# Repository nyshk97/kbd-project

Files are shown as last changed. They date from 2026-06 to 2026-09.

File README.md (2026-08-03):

# kbd-project

自分用の最高のキーボードを作るための、自作分割キーボードプロジェクト。
量産・販売は目的にしない。

## 概要

- 個人利用を最優先し、一般化・量産性・販売価格の最適化は優先しない
- 最終形は**左右分割・ロースタッガード・完全無線**に、**Apple Magic Trackpadを中央に統合**した一体型ケースを目指す
- 電源は**乾電池（エネループ単4×2）**。充電の管理から解放されることを要件にする
- 最初から最終形を作らず、簡単な試作を複数台作って段階的にリスクを潰す
- ファームウェアは**ZMK**、MCUは**Raytac MDBT50Q-1MV2 直付け**、スイッチは**Kailh Choc V2（19mmピッチ）**

方針の変遷と、そう決めた理由は `docs/decisions.md` に記録している。

## 進捗

- [x] 最終形の方向性整理
- [x] 段階試作向けのディレクトリ構成
- [x] p01-simple-split: ZMK + XIAO nRF52840 + Choc v1 + 分割 + 親指キー → **保留**（学習目的は達成済み）
- [x] p02-auto-kdk: Auto-KDKで設計した64キー無線分割 → **保留**（PCBの疎通確認まで。スイッチ未装着で打てる状態ではない）
- [ ] **p03: 中央トラックパッド統合・フルスクラッチ** ← 次に着手
- [ ] target: 最終統合版（p03がそのままtargetになる可能性が高い）

p01・p02は未完成のまま保留としたが、放置ではなく判断として記録している。理由は各 `build-log.md` の「保留」節を参照。

次にやることの詳細は `docs/roadmap.md` を参照。

## ディレクトリ構成

使うものだけを置く最小構成にする。

- `docs/` : プロジェクト全体の方針・ロードマップ・意思決定
  - `decisions.md` : 設計判断とその理由（**このプロジェクトの中心的なドキュメント**）
  - `roadmap.md` : 試作ごとの目的と作業順序
  - `parts.md` / `target.md` : 部品メモ、旧方針の最終形メモ
- `boards/p01-simple-split/` : 初号機（保留）。目的・部品表・作業ログ・ZMK設定
- `boards/p02-auto-kdk/` : 2号機（保留）。Auto-KDK生成データ一式・発注記録・作業ログ
- `target/` : 最終的に目指す統合版。旧方針のKLE/Ergogen成果物はレイアウト検討の参考資料として残す

p03のディレクトリは着手する時点で追加する。まだ使わないディレクトリは作らない。必要になった時点で、各試作機の配下に次を追加する。

- `layout/` : KLEや物理配列メモ
- `pcb/` : KiCadファイル、GerberなどのPCB成果物
- `case/` : ケース3Dデータ、印刷用データ
- `firmware/` : ZMK設定ファイル
- `keycaps/` : キーキャップ3Dデータ

試作をまたいで再利用するものが出てきたら `shared/` を作る。外部資料や生成スクリプトが必要になったら `vendor/` や `tools/` を作る。

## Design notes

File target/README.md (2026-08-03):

# target

最終的に目指す統合版の設計データを置く。

**現状（2026-08-03）**: ここに置いてあるKLEレイアウトとErgogen設定は、**初期の旧方針（Ergogen + KiCadでのフルスクラッチ、Choc v1、トラックボール）に基づく成果物**であり、現行方針とは一致しない。レイアウト検討の参考資料として残している。

現行方針では、キーレイアウトの正本は `../boards/p02-auto-kdk/split-us60pct.json`（Choc V2 19mmピッチ・64キー）。次の試作 p03 でもこれをほぼそのまま使う。

**p03がそのままtargetになる可能性が高い**ため、このディレクトリに新たな成果物を置くかは p03 の進行を見て決める。

関連ドキュメント:

- `../docs/decisions.md` : 設計判断とその理由（現行方針の正本）
- `../docs/roadmap.md` : 試作ごとの目的と作業順序
- `../docs/target.md` : 旧方針の最終形メモ（旧方針と明記済み）

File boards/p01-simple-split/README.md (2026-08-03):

# p01-simple-split

ZMK、XIAO nRF52840、Choc v1、左右分割、親指キーの基本フローを掴むための初号機。

> ⚠️ **2026-08-03: 未完成のまま保留にした。** 下記の目的（ZMKのビルド・書き込み・split設定、Chocソケットのはんだ付け、JLCPCB発注）は**すべて達成済み**で、残るXIAOのdirect mountはんだ付けのみ未実施。完成させない判断の理由と残る資産は `build-log.md` の「保留」節を参照。
> 以下の内容は当時の計画書としてそのまま残している。

## 確定仕様

- 無線分割
- ZMK
- Corne Xiao系42キー
- Kailh Choc v1
- Seeed Studio XIAO nRF52840
- トラックボールなし
- エンコーダーなし
- BLEドングルなし
- XIAO nRF52840 Plusなし

## 目的

- ZMKのビルド、書き込み、左右分割設定に慣れる
- XIAO nRF52840前提のZMK構成と配線に慣れる
- Choc v1の配列、キースペース、親指キー位置を体感する
- レイヤー運用で数字、記号、矢印を扱えるか確認する
- PCB、ケース、ファームウェア、組み立ての一連の流れを短く一周する

## スコープ

やること:

- 左右分割
- 42キー前後
- 親指キー
- ZMK
- Seeed Studio XIAO nRF52840
- Choc v1

やらないこと:

- BLEドングル
- PMW3610トラックボール
- EVQWGD001エンコーダー
- XIAO nRF52840 Plusの追加GPIO検証
- OLED / RGB
- 独自キーキャップ
- 複雑な立体ケース

## 完了条件

- 全キーが入力できる
- 左右分割通信が安定する
- XIAO nRF52840でZMKのビルド、書き込み、ペアリングができる
- 最低限のレイヤーで日常入力を試せる
- 親指キー位置の良し悪しを記録できる

## 選定固定

部品購入やPCB発注の前に、使うCorne Xiao系設計を1つに固定する。

現時点の方針:

- ハードウェア正本: `JonMuller/gerbers` の `corne-choc-xiao`
- ハードウェア参考: `LeducH/corne-choc-xiao`
- ファームウェア出発点: `wintinue/zmk-corne`

理由:

- `JonMuller/gerbers` が `corne-choc-xiao` の元実装として扱いやすい
- `LeducH/corne-choc-xiao` のGerber/BOM/CPLはJonMuller版と同一で、整理版・ガイド・購入リンクの参考に向く
- `wintinue/zmk-corne` は `config/boards/shields/chipper/` を持ち、`chipper_left` / `chipper_right` のshield定義を含む
- `wintinue/zmk-corne` は42キー向きの `default_transform` を選択済み
- `wintinue/zmk-corne` のActionsは2025-12時点で成功実績がある

確認済み:

- `wintinue/zmk-corne` 由来の設定は、current ZMK向けに `xiao_ble//zmk` へ変更済み
- GitHub Actions run `28447236060` で `chipper_left` / `chipper_right` のUF2生成に成功
- JonMuller `corne-choc-xiao` のGerber/BOM/CPLを固定し、発注・購入チェックリストを `parts.md` に作成済み
- JLCPCBへPCB 5枚 + bottom side部分PCBA 5枚を発注済み

残確認:

- JLCPCBのDFM/PCBAレビューで確認依頼が来た場合は、承認前に内容を確認する
- `J8` に合うバッテリー/ケーブルと極性を確認する
- XIAO direct mountと裏面バッテリーパッド配線の手順を確認する
- 電源スイッチのfootprint寸法を購入前に確認する

確認するもの:

- リポジトリURLとcommit
- Gerberの有無
- BOM
- Choc v1対応か
- XIAO nRF52840対応か
- 左右の基板がリバーシブルか、左右別か
- ZMK shield定義の入手方法
- `build.yaml` のboard/shield例
- ZMK Studio対応の有無
- バッテリー端子、電源スイッチ、リセットスイッチの扱い

注意:

- 無印CorneはPro Micro前提なので、Corne Xiao系と取り違えない
- `Corne Xiao` という公式統一shield名があるわけではなく、作者ごとにshield名が違う
- ZMK公式のcurrent targetではXIAO nRF52840のboardは原則 `xiao_ble//zmk`
- shield名は選定した基板repoの `boards/shields/` 定義に従う
- 外部shieldの場合はzmk-config内にshield定義を置くか、ZMK moduleとして取り込む

## 実行手順

1. Corne Xiao系設計を選定固定する
2. 基板の入手方法を決める。完成品を買うか、GerberからJLCPCB等へ発注する
3. `parts.md` に沿ってBOMと購入先を確認し、不足部品を購入する
4. 工具を準備する。温度調整付きはんだごて、はんだ、フラックス、テスター、ピンセットを前提にする
5. ダイオード、ホットスワップソケット、スイッチ、XIAO、電源まわりの順に組み立てる
6. 各キーと電源まわりの導通をテスターで確認する
7. ZMK configを作る。ZMK CLIまたは基板repoのサンプルconfigを起点にする
8. `build.yaml` に左右ターゲットを追加する。boardは原則 `xiao_ble//zmk`、shieldは基板repoの定義名を使う
9. 最小keymapを書く
10. GitHub Actionsでビルドし、左右の`.uf2`を取得する
11. XIAOをブートローダーモードにして左右それぞれへ`.uf2`を書き込む
12. 左右を同時リセットし、split接続を確認する
13. PCとはcentral側、通常は左手だけをBluetoothペアリングする
14. 全キー入力テストを行う
15. keymapを編集、push、再ビルド、再フラッシュして反復する

## ZMKメモ

- 古い記事やサンプルでは `seeeduino_xiao_ble` など旧board名が出ることがある
- current ZMKのXIAO nRF52840 board targetは `xiao_ble//zmk` を前提に確認する
- 実際に使うboard/shield名は、選定したCorne Xiao系repoと現在のZMK公式ドキュメントを優先する
- 分割構成ではcentral側がPCへHID出力する。peripheral側はPCと直接ペアリングしない

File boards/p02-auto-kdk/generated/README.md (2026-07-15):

# split-us60pct

Generated by [Auto-Keyboard-Design-Kit](https://auto-kdk.pages.dev/)

## Preview

- 3D View

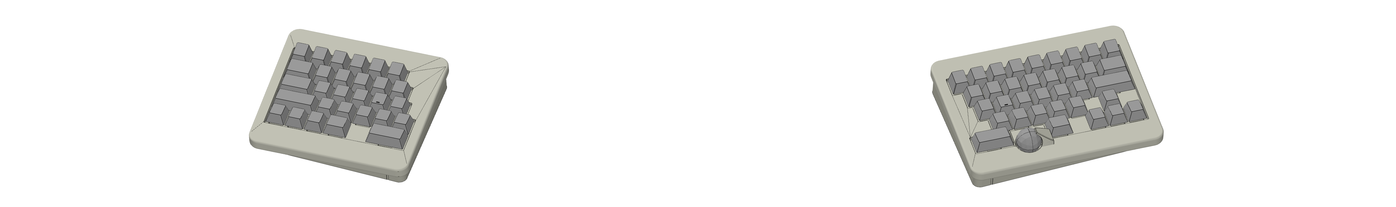
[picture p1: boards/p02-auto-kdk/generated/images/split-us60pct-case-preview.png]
Case Preview


- Top View

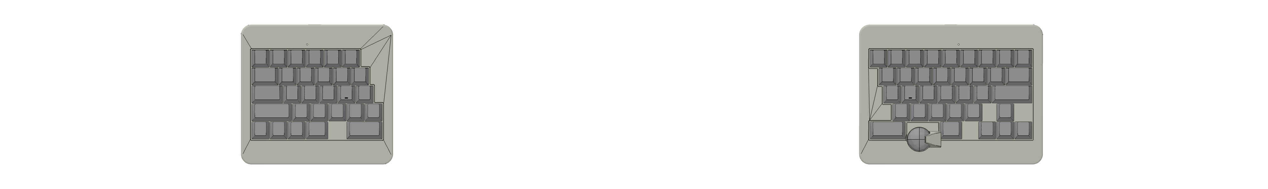
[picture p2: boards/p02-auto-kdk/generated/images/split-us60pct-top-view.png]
Top View


## Parts List

|Part|Quantity|
|---|---|
|wireless controller|2|
|Conthrough(2.5mm, 9pin)|4|
|Battery|2|
USB-C cable|1|
|Choc V2 switch and Choc socket|64|
|Diode|64|
|Keycap|64|

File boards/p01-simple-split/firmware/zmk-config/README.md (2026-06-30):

# **ZMK Firmware for Corne Keyboard (XIAO BLE)**

This repository contains a customized **[ZMK firmware](https://zmk.dev/docs)** for the **Corne split keyboard**(42 keys) powered by **[Seeed Studio XIAO BLE](https://wiki.seeedstudio.com/XIAO_BLE/)**. It includes a custom keymap, multiple layers, and Bluetooth multi-device support.

## **Features**
- 🛠 **Custom Keymap** optimized for efficiency and ergonomics.
- 🔄 **Multiple Layers**: macOS, Windows, Symbols, Numbers, System, and Mouse.
- 📡 **Bluetooth Multi-Device Support** for seamless switching between up to 5 devices.
- 🎭 **Tap & Hold Behavior** for dual-function keys.
- 🖱 **Mouse Layer** for cursor movement and scrolling.
- 🔄 **Firmware Reset & Bootloader Access** via dedicated keys.

---

## **Getting Started**

### **1️⃣ Fork This Repository**

### **2️⃣ Customize Keyboard**
- Using GUI
  - [Keymap Editor](https://nickcoutsos.github.io/keymap-editor/)
- Edit code
  - Edit [`config/chipper.conf`](https://github.com/wintinue/zmk-corne/blob/custom/config/chipper.conf) to set your own keyboard
  - Edit [`config/chipper.keymap`](https://github.com/wintinue/zmk-corne/blob/custom/config/chipper.keymap) to set your own keymap

### **3️⃣ Build Firmware**
1. Click `Action` tab of your repository page.
2. Run `Build ZMK firmware` workflow.
3. Download firmware zip file.

### **4️⃣ Flash Firmware**
1. **Put XIAO BLE into bootloader mode** by double-tapping the [**RST** button](https://wiki.seeedstudio.com/XIAO_BLE/#hardware-overview).
2. Drag and drop the generated `.uf2` file into the mounted **bootloader drive**.

---

## **Keymap Overview**

### **Layer Structure**
| Layer | ID | Function |
|---|----|---|
| **macOS** | `MAC 0` | Default macOS typing layer |
| **Windows** | `WIN 1` | Default Windows typing layer |
| **Symbols & Functions** | `SYM 2` | Special characters, function keys (F1-F12) |
| **Numbers & Navigation** | `NUM 3` | Number pad, navigation keys |
| **System** | `SYS 4` | Media controls, Bluetooth switching, bootloader, reset |
| **Mouse** | `PNT 5` | Mouse movement, scrolling |

---

### **Layer Details**

#### **1️⃣ macOS Layer (`MAC 0`)**
```
 ┌─────┬─────┬─────┬─────┬─────┬─────┐      ┌─────┬─────┬─────┬─────┬─────┬─────┐
 │ TAB │  Q  │  W  │  E  │  R  │  T  │      │  Y  │  U  │  I  │  O  │  P  │BSPC │
 ├─────┼─────┼─────┼─────┼─────┼─────┤      ├─────┼─────┼─────┼─────┼─────┼─────┤
 │CTRL │  A  │  S  │  D  │  F  │  G  │      │  H  │  J  │  K  │  L  │  ;  │CTRL │
 │ ESC │     │     │     │     │     │      │     │     │     │     │     │ '   │
 ├─────┼─────┼─────┼─────┼─────┼─────┤      ├─────┼─────┼─────┼─────┼─────┼─────┤
 │SFT  │  Z  │  X  │  C  │  V  │  B  │      │  N  │  M  │  ,  │  .  │  /  │SFT  │
 └─────┴─────┴─────┼─────┼─────┼─────┤      ├─────┼─────┼─────┼─────┴─────┴─────┘
                   │GUI  │SYM  │SPACE│      │RET  │NUM  │ALT  │
                   └─────┴─────┴─────┘      └─────┴─────┴─────┘
```
- Standard QWERTY layout with `Cmd` (`LGUI`) instead of `Ctrl`.
- **Left Ctrl (`LCTRL`) is dual-purpose**:
  - Tap → `Esc`
  - Hold → `LCTRL`

#### **2️⃣ Windows Layer (`WIN 1`)**
- Identical to macOS, but `Ctrl` and `Win` keys are swapped to match Windows shortcuts.

#### **3️⃣ Symbols & Functions (`SYM 2`)**
```
 ┌───────┬───────┬───────┬───────┬───────┬───────┐      ┌───────┬───────┬───────┬───────┬───────┬───────┐
 │  ~    │  !    │  @    │  #    │  $    │  %    │      │  ^    │  &    │  *    │  (    │  )    │TRANS  │
 ├───────┼───────┼───────┼───────┼───────┼───────┤      ├───────┼───────┼───────┼───────┼───────┼───────┤
 │ PNT   │  F1   │  F2   │  F3   │  F4   │  F5   │      │  F11  │  -    │  =    │  [    │  ]    │  |    │
 ├───────┼───────┼───────┼───────┼───────┼───────┤      ├───────┼───────┼───────┼───────┼───────┼───────┤
 │TRANS  │  F6   │  F7   │  F8   │  F9   │  F10  │      │  F12  │  _    │  +    │  {    │  }    │  \    │
 └───────┴───────┴───────┼───────┼───────┼───────┤      ├───────┼───────┼───────┼───────┴───────┴───────┘
                         │TRANS  │TRANS  │TRANS  │      │TRANS  │SYS    │TRANS  │
                         └───────┴───────┴───────┘      └───────┴───────┴───────┘
```
- **Function keys (`F1-F12`)**
- **Symbol characters** (`@ # $ % ^ & * ...`)

#### **4️⃣ Numbers & Navigation (`NUM 3`)**
```
 ┌───────┬───────┬───────┬───────┬───────┬───────┐      ┌───────┬───────┬───────┬───────┬───────┬───────┐
 │  `    │  1    │  2    │  3    │  4    │  5    │      │  6    │  7    │  8    │  9    │  0    │TRANS  │
 ├───────┼───────┼───────┼───────┼───────┼───────┤      ├───────┼───────┼───────┼───────┼───────┼───────┤
 │TRANS  │ CAPS  │ HOME  │ PGUP  │ DEL   │       │      │ LEFT  │ DOWN  │  UP   │RIGHT  │  |    │TRANS  │
 ├───────┼───────┼───────┼───────┼───────┼───────┤      ├───────┼───────┼───────┼───────┼───────┼───────┤
 │TRANS  │ PSCRN │ END   │ PGDN  │ INS   │       │      │       │       │TRANS  │TRANS  │  \    │TRANS  │
 └───────┴───────┴───────┼───────┼───────┼───────┤      ├───────┼───────┼───────┼───────┴───────┴───────┘
                         │TRANS  │SYS    │TRANS  │      │TRANS  │TRANS  │TRANS  │
                         └───────┴───────┴───────┘      └───────┴───────┴───────┘
```
- **Number keys (`1-0`)**
- **Navigation keys (`Home, End, PgUp, PgDn`)**
- **Arrow keys (`Left, Right, Up, Down`)**

#### **5️⃣ System (`SYS 4`)**
```
 ┌───────┬────────────┬───────┬──────────┬──────────┬───────┐      ┌───────┬───────┬───────┬───────┬───────┬────────┐
 │       │ Play/Pause │ Mute  │ Show Win │ Show App │       │      │       │MAC    │WIN    │       │       │ BT_CLR │
 ├───────┼────────────┼───────┼──────────┼──────────┼───────┤      ├───────┼───────┼───────┼───────┼───────┼────────┤
 │       │ Next       │ Vol+  │ Bright+  │ Search   │ Boot  │      │ Boot  │  BT0  │ BT1   │ BT2   │ BT3   │ BT4    │
 ├───────┼────────────┼───────┼──────────┼──────────┼───────┤      ├───────┼───────┼───────┼───────┼───────┼────────┤
 │       │ Prev       │ Vol-  │ Bright-  │          │ Reset │      │ Reset │       │ BT_PRV│ BT_NXT│       │        │
 └───────┴────────────┴───────┼──────────┼──────────┼───────┤      ├───────┼───────┼───────┼───────┴───────┴────────┘
                              │          │TRANS     │       │      │       │TRANS  │       │
                              └──────────┴──────────┴───────┘      └───────┴───────┴───────┘
```
- **Media controls** (`Play/Pause, Volume, Brightness`).
- **Bluetooth switching:**
  - `BT_SEL 0-4` → Switch to paired devices.
  - `BT_CLR` → Clear Bluetooth pairing.
  - `BT_PRV / BT_NXT` → Cycle through devices.
- **Firmware reset & bootloader mode:**
  - `sys_reset` → Soft reset.
  - `bootloader` → Enters bootloader for flashing firmware.

#### **6️⃣ Mouse (`PNT 5`)**
```
 ┌───────┬───────┬───────┬───────┬───────┬───────┐      ┌───────┬───────┬───────┬─────────┬───────┬───────┐
 │       │       │       │       │       │       │      │ ScrL  │ ScrD  │ ScrU  │ ScrR    │       │       │
 ├───────┼───────┼───────┼───────┼───────┼───────┤      ├───────┼───────┼───────┼─────────┼───────┼───────┤
 │       │       │       │       │       │       │      │ Left  │ Down  │ Up    │ Right   │       │       │
 ├───────┼───────┼───────┼───────┼───────┼───────┤      ├───────┼───────┼───────┼─────────┼───────┼───────┤
 │       │       │       │       │       │       │      │ Back  │       │       │ Forward │       │       │
 └───────┴───────┴───────┼───────┼───────┼───────┤      ├───────┼───────┼───────┴─────────┴───────┴───────┘
                         │       │       │       │      │ LClick│ RClick│ MClick│
                         └───────┴───────┴───────┘      └───────┴───────┴───────┘

```
- **Mouse cursor movement (`MOVE_UP, MOVE_DOWN, MOVE_LEFT, MOVE_RIGHT`)**
- **Scrolling (`SCRL_UP, SCRL_DOWN, SCRL_LEFT, SCRL_RIGHT`)**
- **Mouse clicks (`LCLK, RCLK, MCLK`)**
- **Shortcut keys for browser navigation (`C_AC_BACK, C_AC_FORWARD`)**

---

## **Bluetooth Multi-Device Pairing**

XIAO BLE supports pairing with up to **5 devices**.

### **Pairing New Devices**
1. Activate the **SYS layer** using the assigned key.
2. Select a Bluetooth slot (`BT_SEL 0-4`).
3. Put the keyboard in pairing mode (`BT_CLR`).
4. Connect via your device’s Bluetooth settings.

### **Switching Between Devices**
Once paired, switch devices using:
- `&bt BT_SEL 0` → Device 1
- `&bt BT_SEL 1` → Device 2
- `&bt BT_SEL 2` → Device 3
- `&bt BT_SEL 3` → Device 4
- `&bt BT_SEL 4` → Device 5

---

## **Firmware Reset & Bootloader**

- **Reboot Keyboard:** Press the **reset key** (mapped in `SYS` layer).
- **Enter Bootloader Mode:** Press the **bootloader key** or double-tap the **RST** button.

🔹 `&sys_reset` → Soft reset (restarts the keyboard)
🔹 `&bootloader` → Enters bootloader mode for flashing firmware

- After reset the keyboard, press Space + P | Z to turn on SYS layer
- Further keymap for reset keymap: https://github.com/wintinue/zmk-corne/blob/main/config/boards/shields/chipper/chipper.keymap
---

## **Contributing**
Feel free to submit **issues** or **pull requests** for improvements!

---

## **Credits**
Built using [ZMK Firmware](https://zmk.dev) and inspired by the [Corne Keyboard](https://github.com/foostan/crkbd).

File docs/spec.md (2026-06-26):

# 仕様まとめ

## レイアウト

| 項目 | 内容 |
| ---- | --- |
| 分割 | 左右分割、ロースタッガード |
| 左手 | 6列×5行 + EVQWGD001エンコーダー（escの左） |
| 右手 | 7列×5行 + PMW3610トラックボール（親指エリア） |
| 配列 | US配列、FNキーなし、英数・かなキーなし |

KLEレイアウトはキー数・キー順・ラベルの基準として扱う。Ergogen上の物理座標、列スタッガー、親指キー位置、トラックボール位置は1:1印刷プロトタイプで確認しながら調整する。

## KLEレイアウト

### 左手側

```json
[{a:5,f:5},"`\n~","!\n1","@\n2","#\n3","$\n4","%\n5"],
[{x:0.5,a:7,f:5},"tab","Q","W","E","R","T"],
[{x:0.75,a:4,f:2},"ctrl",{a:7,f:5},"A","S","D","F","G"],
[{x:1.25,a:4,f:2},"shift",{a:7,f:5},"Z","X","C","V","B"],
[{x:1.5,a:4,f:2},"esc","caps","opt","⌘","space"]
```

### 右手側

```json
[{a:5,f:5},"^\n6","&\n7","*\n8","(\n9",")\n0","\"\n'","+\n="],
[{x:0.5,a:7,f:5},"Y","U","I","O","P",{a:5},"{\n[","}\n]"],
[{x:0.75,a:7,f:5},"H","J","K","L",{a:4,f:2,w:1.5},"Enter","_\n-",{a:5,f:5},":\n;"],
[{x:1.25,a:7,f:5},"N","M","<\n,",">\n.","?\n/","↑","|\n\\"],
[{x:1.5,a:4,f:2},"space","⌘","opt",{x:0.75,a:7},"←","↓","→"]
```

## 入力デバイス

| 項目 | 内容 |
| --- | --- |
| スイッチ | Kailh Choc v1 Red（リニア） |
| トラックボールセンサー | PMW3610 |
| トラックボール基板 | SideraKB PMW3610 PCB Rev 2.x系互換 |
| トラックボール径 | 34mm |
| トラックボールクリック | Auto Mouseレイヤー（J・Kキー） |
| スクロール | ボタン押しながらボール転がす |
| エンコーダー | EVQWGD001（左手のみ）レイヤー0=音量、レイヤー1=輝度 |

## 接続・ファームウェア

| 項目 | 内容 |
| --- | --- |
| ファームウェア | ZMK |
| 左右間通信 | BLE |
| PCとの接続 | BLEドングル（USB挿しっぱ） |
| MCU | nice!nano v2 × 3（左右 + ドングル） |

## PCB・ケース

| 項目 | 内容 |
| --- | --- |
| PCB設計フロー | Ergogen → FreeRouting → KiCad最終調整 |
| Ergogen初期成果物 | キー配置 + 外形 + 1:1印刷用アウトライン |
| トラックボール領域  | 34mm円 + 46mm keepout円 + 23.5mm×31.5mm基板矩形 |
| PCB発注 | JLCPCB |
| ケース（フェーズ1） | 3Dプリント（PLA/PETG）、DMM.make or JLCPCB発注 |

## キーキャップ

| 項目 | 内容 |
| --- | --- |
| 1Uキー | MBK市販品（印字なし、フェーズ1） |
| Enterキー（1.5U） | 3Dプリント自作（Choc v1ステム）  |

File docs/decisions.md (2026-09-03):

# 意思決定の記録

## プロジェクト目的：自分用の最高のキーボード

- このプロジェクトは自分用の最高のキーボードを作ることを目的にする
- 量産・販売・第三者向けキット化は目的にしない
- 一般的な使いやすさより、自分の手・作業環境・好みに合うことを優先する
- 部品単価、入手性、製造容易性は考慮するが、量産時の原価最適化やサプライチェーン安定性は優先しない
- 販売向けの認証、パッケージング、ユーザー向け組み立て性、販売後サポートのための設計は対象外にする
- BLE無線モジュールの使用地ごとの法令適合は、販売有無と別に部品選定時に確認する

## 進め方：段階試作

- 最終形を一度で作らず、簡単な試作を複数台作って段階的に近づける
- 各試作機は `boards/pXX-*` に分け、目的・部品表・作業ログを個別に持つ
- 最終形の設計データは `target/` に置き、試作で検証できた要素だけを反映する
- まだ使わないディレクトリは先に作らず、必要になった時点で追加する
- 試作をまたいで使うZMK設定、Ergogen定義、footprint、ケース部品が出てきたら `shared/` を作る

### p01・p02は未完成のまま保留にする（2026-08-03決定）

**両方とも「完成させない」と決めた。** 放置ではなく判断として記録する。各機の詳細は `boards/pXX-*/build-log.md` の「保留」節を参照。

- **p01**: 学習目的（ZMK・split疎通・ソケットはんだ・JLCPCB発注とPCBAのBOM/CPL）は**すべて達成済み**。残るXIAOのdirect mountはんだ付けは、p03では自分のPCBにMCUを載せる設計をするため転用価値が薄い。かつCorne系42キーの別配列は日常運用に投入できず、「1週間使ってみる」ができない。完成させて得られるのは達成感のみと判断
- **p02**: 残作業（バッテリー極性の再工作・トラックボールのモジュール再購入・本番スイッチ64個¥5,000）に対して、得られる検証結果が見合わない。**p03の設計に必要な実測値（左右間隔・奥行きの揃え方・トラックパッド面との高さ差）は、結局p03の実物を3Dプリントして手を乗せないと決まらない**ため、p02を完成させても代替にならない
  - p02で唯一固有に分かるのは**スタビなし幅広キー（2U/2.25U）の実用性**のみ。これは検証対象が4箇所＋比較用1Uが数個なので、**打ち比べで買ったサンプル軸の余りで足りる**（64個の発注は不要）。~~キーキャップが届いた時点で数個だけ挿して確かめる~~ → **検証済み・合格（2026-08-04）**。詳細は「p02レイアウト流用」セクション参照
  - **p02のケース実物は、p03の配置検討モックアップとして価値が残る**（左右間隔・高さを実寸で再現できる唯一の現物）
- 本番スイッチ（~~Pink Island~~ → Islet に変更 2026-08-04）64個の発注は、**p03のキー数とレイアウトが確定してから**行う。先に発注するとp03のPCB論点（XIAOでキー数を減らす vs MDBT50Q直付け）の結論次第で作り直しになる → **レイアウト確定（2026-08-04）により発注可能になった**。YUZUキーキャップは到着済み

## ファームウェア：ZMK

- 完全無線・省電力・Auto Mouseレイヤー・エンコーダー対応が全部揃う
- QMKは有線前提のため非対応
- p01のZMK configはZMK CLIまたは選定したCorne Xiao系repoのサンプルconfigを起点にする
- current ZMKではXIAO nRF52840のboard targetは原則 `xiao_ble//zmk` として確認する
- 古い記事やrepoに残る `seeeduino_xiao_ble` などのboard名は、そのまま使える前提にしない
- Corne Xiao系のshield名は作者ごとに違うため、選定した基板repoの `boards/shields/` 定義を正とする
- 外部shieldはzmk-config内に置くか、ZMK moduleとして取り込む
- 分割構成ではcentral側がPCへHID出力する。peripheral側はPCと直接ペアリングしない
- p01のハードウェア正本は `JonMuller/gerbers` の `corne-choc-xiao` にする
- `LeducH/corne-choc-xiao` は同一Gerber/BOM/CPLの整理版として、ガイド・購入リンクの参考に使う
- p01のファームウェア出発点は `wintinue/zmk-corne` にする
- `wintinue/zmk-corne` の `chipper_left` / `chipper_right` shield定義を起点にし、`build.yaml` のboard名をcurrent ZMK向けに確認・修正する

## MCU：p01はXIAO nRF52840、targetはAuto-KDK専用無線ボード

- p01は無印XIAO nRF52840を使う（変更なし。既存のCorne Xiao系シールドをそのまま使える）
- targetはAuto-KDK採用（2026-07-15、下記PCB設計方針を参照）に伴い、専用無線コントローラボード（nRF52840、IO 18ピン・うち4ピンは拡張モジュールと共用）に変更する
- 専用ボードはBOOTH（のぎけす屋）で無線2個セット¥9,000。一体型・分割とも1セットでよい。コンスルー同梱ではんだ付け不要
- 電源はPHコネクタの1S Li-Po（保護回路必須）、充電200mA、バッテリー最大6×31×52mm
- 旧方針（target向けXIAO nRF52840 Plus候補）は不要になったため撤回

## 接続方式：まずBLE直結、必要になったらドングル追加

- 旧方針はBLEドングル前提（BLE直結はMacとの相性問題・スリープ復帰約5秒の懸念、ドングルはUSB常時接続でほぼ即時復帰）
- p02はBLE直結で使い始める方針に変更（2026-07-15）。ドングルの有無はハードウェアに影響せず、後からファームウェアのビルドターゲット追加＋手持ちの余りXIAO nRF52840の転用だけで移行できるため、スリープ復帰の遅さを実際に体感してから判断する
- ドングル構成がビルド可能かの検証はzmk-config-split-us60pctリポジトリのdongleブランチで実施（dongle/right_p shield、input-splitによるトラックボール中継、XIAOドングル対応）

## スイッチ：p01はChoc v1 Red、targetはChoc V2（19mmピッチ）

- 旧方針はChoc v1 Red（ロープロ最薄・Macの打鍵感に最も近い）だったが、Auto-KDKがChoc v1非対応のため覆した（2026-07-15）
- targetはChoc V2・19mmピッチ。MacBookのキーピッチ（約19mm）を維持して運指の記憶を移行する
- Choc V2はトータルトラベル約3.2mm（バリアントにより2.8mm）・アクチュエーション約1.3mmで、ロープロ最短クラス。MacBook（約1mm）の完全再現ではなく「メカニカルで到達できる最良の近似」と割り切る
- 軸（バリアント）はPCB・ケース設計に影響しないため後から決める。MacBook近似の観点で軽めリニア（Deep Sea Mini Pink Island 35gf / Islet 43gf / Red 45gf前後）を打ち比べ候補にする
- **軸は Kailh Deep Sea Silent MINI Islet（43gf 静音リニア）に決定（2026-08-04）**。YUZUキーキャップ到着後、p02実機にキーキャップ込みで挿して打ち比べた結果 Islet が最良（遊舎工房商品名「Kailh Deep Sea Low Profile Choc V2 サイレントスイッチ 1353 RGB MINI」のIsletバリアント）。~~2026-08-02にキーキャップなしの素のPCB打鍵で Pink Island（35gf）に決定~~ したが、キーキャップの質量が乗ると評価が逆転した（結果的に2026-07-15の当初本命Isletに戻った）。**軸の評価は素のステム打鍵では決まらない。必ずキーキャップを装着して打ち比べる**。「43gf前後の軽めロープロ静音リニアが好み」という知見はステム規格に依存しないため、完成版でMX規格に変えることになっても同等品を指名買いできる
- Choc V2はMXステム。キーキャップ自作はフラット・薄型・広めを狙うとMacBook感が出る
- Choc v1とV2は物理非互換（PCBセンター穴径が違う）ため、p01のPCBにV2は刺さらない。ホットスワップソケット自体は共通で、p01のソケット検品知見は活きる
- 2U以上のキーにはスタビライザーが必要。Choc V2対応ロープロスタビの入手性を確認し、入手困難なら2U以上のキーを置かないレイアウト（親指2Uを分割等）に逃がす

## トラックボールセンサー：PAW3222（target）

- 旧方針のPMW3610（＋SideraKBボード＋34mm固定）はAuto-KDKで選べないため、Auto-KDK標準のPAW3222に覆した（2026-07-15）
- PAW3222は低消費電力で、ZMKドライバ（zmk-driver-paw3222）を開発者sekigon-gonnoc氏自身がメンテしている。無線・バッテリー持ち重視というPMW3610選定理由をそのまま満たす
- ボール径34mm固定は撤回。Auto-KDKのバリエーション（thumb-25 / thumb-34 / index-25〜50）から実配置で選ぶ。径へのこだわりはない
- トラックボール使用時は無線ボードのIOを4ピン消費する（18→実質14）
- **p02では搭載を見送り（2026-08-02）**: 組み立て中にセンサーモジュールのFFCコネクタのラッチを破損。再購入（BOOTH ¥4,500・納期）に見合わないと判断し、キーボード部分の完成を優先した。ボール・支持球・FFC・木工用ボンドは未使用のまま保管してあるので、モジュールだけ買い直せば後から追加できる（ケースにトラックボール穴と支持球座は造形済み）
- **完成版のポインティングデバイスは再検討（未確定 2026-08-02）**: トラックパッドを使う方向で検討中。Auto-KDKはトラックパッドにも対応している（`manual/Trackpad.md`）。ただしp02でトラックボールを実地評価できなかったため、比較材料がない状態での判断になる点は認識しておく。なお中央Magic Trackpad案とトラックボールは**排他ではない**（下記「中央トラックパッド統合ケースの設計メモ」参照）ので、トラックボールを捨てる判断を今する必要はない

## エンコーダー：搭載しない

- 旧方針はEVQWGD001（縦回転スクロールホイール）だったが、必要性が薄れたため搭載しない方針に変更（2026-07-15）
- Auto-KDKにエンコーダーの選択肢がない（EC11・EVQWGD001とも非対応）ことも整合する
- スクロールはトラックボール＋ZMKのスクロールレイヤーで代替する想定

## PCB・ケース設計方針：Auto-KDK

- 旧方針（Ergogen + FreeRouting + KiCad のフルスクラッチ）を覆し、targetはAuto-KDK（sekigon-gonnoc氏のWebツール https://auto-kdk.pages.dev/ ）で設計する（2026-07-15に調査のうえ決定）
- 決定理由: レイアウト指定からPCB（EasyEDA形式json→JLCPCB発注）・ケースSTL・ZMK shield一式（ZMK Studio対応）・フォームカットSVGまで自動生成でき、要件（分割・無線ZMK・ロースタッガード・トラックボール）をネイティブに満たす。特にケース設計の学習コストを丸ごと消せる
- 2026年6月ビルド（ver 2026-06-03）が稼働中のアクティブなプロジェクト。製造到達したユーザー事例も複数あり
- 制約として受け入れたもの:
  - 専用コントローラボード必須（XIAO等の市販MCUボードは選べない）
  - 無線はrow+col合計18ピン上限。トラックボール使用側は実質14ピンで、5行×9列だと上限ちょうど（キー追加不可）
  - PCBデータはEasyEDA形式のためKiCadでの手直し不可。手直しはEasyEDA上で行う
- 未解決事項の確認結果（2026-07-15、データ生成zipで確認）:
  - ライセンス: 解決。利用規約により個人利用・商用利用とも可。ただし生成データは**Auto-KDK公式コントローラとの組み合わせでのみ使用可**。現状有姿・無保証
  - ホットスワップ: 解決。生成PCBにKailh Chocソケット（CPG135001S30）×64 + 1N4148W×64のフットプリントあり。はんだ付けは自分で行う
  - 左手PCB: 解決。left/right/panelized（面付け版）の3種のEasyEDA jsonが生成される
  - スタビライザー: フットプリントなしと判明。Choc V2構成では2U/2.25Uキー（左Shift 2.25U・左親指2U・右2U・右Enter 2.25U）がスタビなしになる → **スタビなしのまま行くと決定（2026-07-15）**。ロープロ＋トラベル3mm＋軽量キャップなら実害は小さい見込みで、「スタビなし幅広キーが実用になるか」自体をp02の検証項目にする。ダメなら次イテレーションで幅広キーを1.5U以下に分割（既存マトリクスの空きセルに収まるためピン数制約には抵触しない）
  - ドングル対応: 解決。zmk-config-split-us60pctのdongleブランチで、dongle shield（central役・モックkscan）＋right_p shield（右手peripheral化・トラックボールをzmk,input-splitで中継）を追加し、akdk_bt1ドングル/XIAOドングル（ZMK v0.3では board名 `seeeduino_xiao_ble`。`xiao_ble//zmk` は新しいZMK mainの名前でv0.3では無効）とも全ターゲットビルド成功（2026-07-15）。必要になったらこのブランチをmainに取り込むだけ
  - 自動配線の品質: 未検証（EasyEDAインポート時に確認）
- 旧方針のErgogen成果物（キー配置・1:1印刷アウトライン）とKLE基準は、レイアウト検討の参考資料として残す

## キーマップ：トラックパッドジェスチャの代替はZMKコンボ

> **完成版では不要になる見込み（2026-08-02）**: Magic Trackpadをケースにはめ込む方針にしたため、macOSのジェスチャーがそのまま使える。下記のコンボはp02（トラックパッドなし構成）でのみ意味を持つ。

- トラックパッド廃止に伴い、4本指スワイプ相当の操作はmacOS標準ショートカット（Ctrl+矢印）をコンボで送る（2026-07-15）
  - J+K = Ctrl+←（左のスペースへ）
  - K+L = Ctrl+→（右のスペースへ）
  - J+K+L = Ctrl+↑（Mission Control。トグルなので閉じるのも同じコンボ）
- Ctrl+↓（App Exposé）は不要と判断。恋しくなったらM+,+.（JKLの真下段）に追加する
- 誤発動対策はrequire-prior-idle、3キー同時が押しにくければtimeout-msを50→80ms程度に調整
- コンボはZMK Studioでは編集できないため`.keymap`に記述してGitHub Actionsでビルドする。レイヤー・キー割り当ての試行錯誤はStudio、確定したコンボはkeymap、という分担

## ケース（フェーズ1）：3Dプリント

- 動作確認フェーズは速度・コスト優先
- DMM.make or JLCPCBに発注
- フェーズ2の素材（アルミ削り出し等）はフェーズ1完了後に検討
- マウントタイプはインテグレーテッド（2026-07-15）。追加部品不要で試作が速く、硬めの打鍵感はMacBook近似の目的とも整合する。ガスケット/Tadpoleの柔らかさが欲しいかはp02を打ってから判断
- Choc V2用の土手（switchEmbankment）はオフで確定（2026-07-15）。見た目と防塵だけの違いで打鍵感に影響しないため、気が変わったらケース再印刷で対応
- p02ケースパラメータ（2026-07-15確定）: チルト5°、テント4°、底面厚さ3mm（強度優先で1.8mmから戻した）、底面縁幅5mm、上面縁幅3mm、角の種類=丸型、R面取り（上部2mm、下部3mm=接地際を削って薄く見せる）。MacBook寄りの柔らかい外観狙い。全てケースSTLのみに影響するため、実物を見て気に入らなければ再印刷で調整

## 完成版の方向性（2026-08-02 更新）

p02を組み上げた経験を踏まえた、完成版の要件イメージ。まだ設計に入る前の方向性であり確定ではない。

### 前提の裏付け：Nuio Flow + Magic Trackpad の実運用経験（2026-08-03 記録）

**「分割キーボードの中央にトラックパッド」という配置は、すでに実運用で検証済み**だった。以前 Nuio Flow（マグネットのデスクパッド上に分割キーボードとトラックパッドを配置するシステム。キーボード$400〜、フルセット$1,000超）と自前の Magic Trackpad を組み合わせて使っていた。

現在は使っておらず手放しているが、**その理由は配置への不満ではなく、周辺の運用への不満だった**：

| 手放した理由 | p03での扱い |
|---|---|
| Nuioの接続が不安定だった | Nuio固有の問題。自作＋ZMKなら自分で制御でき、ドングル構成のビルド検証も済んでいる |
| 充電の管理が面倒だった | **乾電池案（案B）が直接の回答**（下記「薄型化・電源方式」参照。この経験により案Bを本命に格上げ） |
| 机の上にPCの他にキーボード左右＋トラックパッドの3つが増えてごちゃつく | **一体化ケースが直接の回答**。3個バラバラより机がすっきりするという期待がp03の動機そのもの |

**この経験は「トラックパッドを中央に置く配置が自分に合うか」というp03最大の前提リスクを潰している。** 配置は気に入っていて、嫌だったのは接続・充電・散らかりの3点。p03はその3点すべてに設計上の回答を持っている。

なお `docs/decisions.md` の「トラックボールセンサー」の項に「p02でトラックボールを実地評価できなかったため比較材料がない状態での判断」と書いたが、**トラックパッド側については比較材料がないどころか一次の実運用データがある**、と補正する。未評価なのはトラックボールの側。

### 外部キーボードの重要度が上がった（2026-08-03）

Nuio運用時は Mac 1台（MacBook）だけだったが、現在は**自分のMacBook・案件で支給されたMacBook**の2台で、さらに**常時稼働のmac miniを追加予定**。複数台を1組の入力デバイスで扱う必要が出たため、外部キーボードの重要度が当時より上がっている。この変化は下記「複数Mac運用とデバイス切り替え」の論点を生む。

- **トラックパッド + キーボードが一体で綺麗に収まるケース**を自作する。ポインティングデバイスはトラックボールからトラックパッドへ変更を検討（p02でトラックボールを実地評価できなかったため、比較材料がない状態での判断である点は認識しておく）
- **3Dプリンターを導入**してケースを内製する。動機は、p02でJLC3DPに外注したケースが「思ったよりゴツい」と実物で分かったこと。外注は1回$155＋納期がかかり試行回数を稼げないため、手元で回せるようにする
- **左右分割・電池駆動・薄型**は維持（下記「薄型化・電源方式」の検討メモを参照）
- p02で使えたChocソケットのはんだ付け・PCB/PCBA発注・コンスルー接続は、もうハードルではないという自己評価（実績: 128箇所で不良の疑い1箇所のみ）

### 完成版で新たに越える必要があるハードル（3Dプリント技術以外、2026-08-02整理）

難度順。詳細は下記「薄型化・電源方式」の検討メモと重複する部分がある。

1. **PCB設計（回路 + アートワーク）**: コントローラ直付け化＝nRF52840モジュール（Raytac MDBT50Q等）を自分の基板に載せる。アンテナのキープアウト設計を外すとBLEが飛ばず、PCB再発注になる。技適はモジュールの認証でカバーされるが、認証条件どおりのアンテナ周辺設計が前提
   - **2026-08-03: 「最大の壁」という評価を下げる。** 下記「MCUの選択肢」の調査で、失敗リスクを発注前に潰す手段が3つ揃っていることが分かったため（Raytacの無料レイアウトレビュー・公開リファレンス設計・干渉源から離せる配置の自由度）。詳細はそちらを参照
2. **ZMKのボード定義自作**: Auto-KDKは `akdk_bt1` のボード定義を提供してくれていた。自作基板ではZephyrのboard定義（dts / Kconfig / defconfig）を自分で書く必要がある
   - **2026-08-03: 難度が下がった。** `boards/p02-auto-kdk/generated/boards/arm/akdk_bt1/` に生成済みのボード定義一式（dts / Kconfig / defconfig / board.cmake）が手元にあり、**同じnRF52840モジュール搭載ボードの実例としてテンプレートに使える**。GPIOマップ・バッテリー電圧分圧・LEDと必要な要素が一通り揃っている。ゼロから書くのとは難度が違う
3. ~~**トラックパッドの選定とドライバ**~~ → **Apple Magic Trackpad をはめ込む方針に決定（2026-08-02）**。BLEでMacに直接繋がる独立デバイスのため、ZMK側は一切関与しない。**ドライバ・動作電圧・基板実装のハードルが丸ごと消え、機構設計だけの問題になる**。副次的に、macOSのジェスチャーがフルで使えるため「キーマップ：トラックパッドジェスチャの代替はZMKコンボ」の項（J+K = Ctrl+← 等）は**不要になる**。新たに出る課題:
   - ⚠️ **感圧式（Magic Trackpad 2以降）を選ぶこと**。初代の物理ヒンジ式は手前を押し込んでクリックする構造なので、ケースに固定するとクリックできなくなる
   - **厚み 最厚部 約10.9mm / 最薄部 約4.9mm** が薄型化の下限を決める。ただし「奥が厚く手前が薄い」形状はキーボードのチルト方向と一致するので、楔形として一体化できる可能性がある。実測して断面を描いて検証する
   - Appleは3Dモデルを公開していないため寸法は実測が必要。固定方法（落とし込み+爪 / 磁石 / 上下で挟む）、背面の充電ポートと電源スイッチへの開口
   - **配置は左右分割の中央に決定（2026-08-02）**。使うのは現行モデル（感圧式）。帰結として:
     - Magic Trackpadの幅160mmぶん、**左右のキーボードを離す**ことになる（隙間を入れて実質165〜170mm）。一般的な分割キーボードの間隔（150〜250mm）に収まる範囲で、肩が開く姿勢は人間工学的にはむしろ有利
     - **奥行きはトラックパッド114.9mm に対しp02ケースが147.8mm**と33mm差がある。手前/奥/中央のどこで揃えるかは、親指キーとトラックパッドの距離感に効くので設計時に要検討
     - ~~**厚みを完全に揃えるのは努力目標**（2026-08-02）。電池ぶん膨らむのは許容し、デザイン（面の連続性・傾斜・面取り）で処理する方針~~ → **2026-08-03: 現実的な目標に格上げ。** 電源をエネループ**単4**×2（直径10.5mm）に決めたことで、**Magic Trackpadの最厚部10.9mmとほぼ一致する**ため。加えてMCUをMDBT50Q直付け（約2mm、最薄）に決めており、コンスルー約6mmやXIAO約3.5mmの上乗せも消えた。デザインで処理する方針は引き続き有効だが、「膨らむのを許容する」前提から出発する必要はなくなった
4. **乾電池駆動の電気設計**: エネループ2本＝2.4V。nRF52840自体は1.7〜3.6Vで動くが、**トラックパッドICの動作電圧を要確認**（PAW3222で未確定のまま残った論点と同型）。低電圧時の挙動、ZMKの電池残量レポートの校正も必要
5. **機構設計（3Dプリント技術とは別のスキル）**: 寸法公差・嵌合・電池ボックスの蓋と接点・薄型化による剛性低下。プリンターが使えることと、勘合する設計ができることは別

**軽減策**: 上記1・2はAuto-KDKを使い続ければ丸ごと回避できる（ただしコントローラ直付け化と乾電池は不可）。段階を分けて、まず「Auto-KDK + トラックパッド + 自作ケース」で3と5を潰し、その後にフルスクラッチで1・2・4へ進む道もあった。

→ **2026-08-02: フルスクラッチで行くと決定。** 段階分けはせず、次のプロトタイプから自作PCB + 自作ケースに進む。

**Auto-KDKのケースは今回の構成には使えない**点も判断材料になった。Auto-KDKは左右それぞれ独立したケースを生成するだけで、「左右をつなぐ中央部分」は生成しない。Magic Trackpadを中央にはめ込む一体型ケースにする以上、ケースはどのみち完全自作になる。

### 中央トラックパッド統合ケースの設計メモ（2026-07-30 検討、未確定）

上記ハードル3（Magic Trackpadを中央にはめ込む）を機構面から詰めたメモ。寸法はp02のSTLからの実測・概算。

先行例: **Nakaniwa（中庭）** — ABplus生産技術研究所の60%スプリットキット。中央にMagic Trackpadを置くスペースを持つ一体型（遊舎工房 ¥19,800、2021年） https://akiba-pc.watch.impress.co.jp/docs/news/news/1366764.html

- **固定は「載せるだけ」でよい**: Magic Trackpad 2以降はForce Touch（感圧＋ハプティクス）でクリックに機械可動部がないため、底面を全面支持しても操作感は変わらない。落とし込み+爪や磁石は位置決めのためだけで、クリック機構への逃げは不要
- **傾斜が噛み合う**: トラックパッド表面は手前4.9mm→奥10.9mmで約3°の傾斜があり、p02のチルト5°と方向が同じ。トレイ側で+2°傾ければキー面とほぼ平行にできる
- **必要なリフト量は10〜25mm程度**: p02のキートップは机から手前約20mm・奥内側約30mm強。3Dプリントに無理のない造形量
- **幅がほぼ一致する**: トラックパッド約160×115mmに対し、p02の片手ケースは約160×148mm。左右の間に並べたときの収まりが良い
- **トラックボールと排他ではない**: トラックパッドはMacと直接BLEペアリングする独立デバイスでキーボード側のハード・ファームに影響しないため、後からトラックボールを載せても共存できる（トラックボール = ホームポジションを崩さない細かいポインティング、トラックパッド = ジェスチャ・スクロール、と役割分担）
- **トラックパッド面はキートップとツライチ〜2、3mm低め**が定番（タイピング中の親指誤タッチ回避）。シム／調整脚で±3mm動かせる設計にして実物で追い込む
- 奥の縁にUSB-Cポート＋電源スイッチの逃げ、取り出し用の指掛かり穴を設ける
- 質感の分担: 外装の最終版はJLC3DP SLA（Black Resin）、試行錯誤・土台類は自宅FDM（256mm級ベッドで全パーツ印刷可）

#### ケースの一体化は段階的に上げる

PCBのフルスクラッチは確定だが、**ケースの一体化度合いは安いイテレーションから試す**。最適な左右間隔・角度がまだ実測で分かっていないため。

1. **単独トレイ**: トラックパッドの台のみ。左右キーボードは自由配置のまま
2. **耳付き中央ユニット**: トレイの左右にケース内縁の位置決めガイドを伸ばす
3. **フルベース板**: 左右ケースの底がはまる凹み付きの板。置けば必ず同じ配置が再現される。500mm超の一枚ものは家庭用プリンタでは不可能（JLC3DPでも高価＋反りリスク）なので、中央＋左右翼の3分割印刷をボルト/ダブテールで結合する
4. **完全一体型ケース**: 全部入り筐体。左右間隔・角度・高さの全パラメータが実測で確定した後の最終回答

~~進め方: p02をキーボードとして完成させる → 机上で間隔・角度をしばらく試す → 気に入った配置を実測 → 1の単独トレイから着手~~

> **2026-08-03: この進め方は撤回。** p02は保留とし完成させない（打鍵できる状態にしない）。左右間隔・角度・高さは**p03の単独トレイを3Dプリントして実物で追い込む**方針に変更した。p02のケース実物は、その際の配置検討モックアップとして使う。

### p01/p02の資産の活用可能性（2026-08-02）

**使えるもの:**

- **XIAO nRF52840（p01の予備1個が未使用）**: 使えば**ZMKボード定義の自作（ハードル2）が丸ごと消える**。`xiao_ble//zmk` としてZMK公式サポート、技適取得済み、充電回路内蔵。PCB設計もモジュール直付けよりずっと楽（フットプリントを置いて配線するだけ）
- **ZMK設定の知見**: shield定義・`build.yaml`・GitHub Actionsビルド・キーマップ/コンボ。p01とp02で2回通したのでハードルではない
- **`boards/p01-simple-split/tools/keytest.html`**: キー確認ツール。そのまま使える
- **JLCPCB発注の知見**: Gerber/BOM/CPL、部分PCBA、DFM確認。自分のGerberを出すときに直結
- **Chocソケット（CPG135001S30）**: Choc v1用とV2用で共通。p01の余りは流用可
- **HIOKI 3244-60（テスター）**
- **DTP502535バッテリー2本**: フルスクラッチなら配線を自分で作るので、p02で踏んだ極性問題も起きない
- **p01のPCB（JonMuller/gerbers の corne-choc-xiao）**: レイアウトが違うので直接流用は不可だが、**XIAOのフットプリントと配線の実例**として参照価値がある

**使えないもの:**

- Choc v1 Red スイッチ、MBKキーキャップ（Choc v1ステム用。V2はMXステムで非互換）
- ~~Auto-KDK専用コントローラ2枚（専用ボード前提の設計のため、フルスクラッチでは使えない）~~ → **2026-08-03: 撤回。使える可能性がある**（下記「MCUの選択肢」の案A参照）。ライセンス条項は*生成データ*の使用を縛るものなので、「自作PCB＋公式コントローラ」は生成データを使わない以上、対象外の可能性が高い。ただしコンスルーのピン配置を生成PCBデータから読み取るのはグレーなため、作者への確認が必要

## MCUの選択肢（2026-08-03 全面整理、未決定）

旧「⚠️ XIAOを使う場合のキー数制約」を、選択肢の洗い直しにより差し替え。**当初「XIAO vs MDBT50Q直付け」の二択と整理していたが、実際には5つある。**

### 前提：マトリクスに必要なピン数

「行数 + 列数」で決まる。p02のレイアウト（右手5行×9列）は**14本**。

| | ピン数 | 64キー維持 | ZMKボード定義 | 技適 | 乾電池 | 薄さ | 手元 | 追加費用 |
|---|---|---|---|---|---|---|---|---|
| **A. Auto-KDKコントローラ** | 18 | ○ | **不要（生成済み）** | ○ 済 | ✗ 充電回路内蔵 | ✗ 約6mm | **2枚あり** | **¥0** |
| **B. XIAO 無印** | 11 | ✗ | 不要（公式） | ○ 済 211-220207 | ✗ 充電回路内蔵 | △ 約3.5mm | **3個あり** | **¥0** |
| **C. XIAO Plus** | 20 | ○ | ほぼ不要 | **要確認** | ✗ 充電回路内蔵 | △ | なし | 約¥4,000（$10.40/個） |
| **D. MDBT50Q-1MV2 直付け** | 豊富 | ○ | 要自作（テンプレあり） | ○ 済 | **○ 載せない選択可** | ○ 約2mm | なし | 約¥3,400 |
| **E. charlieplex配線** | — | ピン制約を撤廃 | — | — | — | — | — | — |

- **C（XIAO Plus）**: 11本のスルーホール＋9本のSMDキャステレーション＝多機能ピン20本。**「XIAOだとキー数が減る」という旧前提を覆す**。ただし**技適が未確認**（無印は211-220207で取得済みだが、Plusは基板レイアウトが変わっており同一認証でカバーされるか不明）。**技適がなければ日本で使えないので選択肢ごと消える**。総務省の技適検索かSeeed公式の認証書類で要確認
- **E（charlieplex）**: 他と直交する選択肢。ZMKに `zmk,kscan-gpio-charlieplex` ドライバが実在し、n本のピンで n×(n-1) キー（interrupt-gpios使用時は (n-1)×(n-2)）を駆動できる。**XIAO無印の11ピンでも90キー**。ただし配線が複雑になりPCB設計の難度が上がる
- 旧案の**I/Oエキスパンダ**は、Eのほうが素直なため優先度を下げる

### 価格差は判断材料にならない

**最大差が¥4,000**で、プロジェクト全体（3Dプリンター¥126,000 / Magic Trackpad ≒¥19,800 / PCB+PCBA $100〜200 / スイッチ¥5,000 / キーキャップ≒¥10,000）の1〜2%にすぎない。**MCU選択を価格で決めるのは筋が悪い。**

実質的なコスト差は別のところにある — **Dの本当の価格は「アンテナ設計を外したときのPCB再発注」（$100〜200＋納期2〜3週間）**であり、部品代¥3,400よりずっと大きい。ただし下記の通り、これは事前に潰せる。

参考価格: A = 2個セット¥9,000（BOOTH）/ B = ¥1,780（秋月、3個¥5,340の実績）/ C = $10.40（Seeed、10個以上で$8.40）/ D = ¥1,185（マルツ）〜¥1,265（スイッチサイエンス）＋周辺部品¥350〜500/枚（USB-Cレセプタクル・ESD保護・リセットSW・電源SW・デカップリング・分圧抵抗。**乾電池直結ならレギュレータと充電ICは不要**）

### 決定的な論点：乾電池と充電回路の衝突

**A・B・C はいずれもLi-Po用の充電回路を内蔵している。** 乾電池を繋ぐとUSB接続時に充電ICがエネループへリチウム用の充電プロファイルを流すことになり危険。さらに電圧の成立性も既製ボードでは保証されない:

| | 給電経路 | 2.4Vで成立するか |
|---|---|---|
| A | PHコネクタ → 充電IC → ? | **回路図が非公開**。LDOが入っていればドロップアウトで不安定。確認手段が実測しかない |
| B/C | BAT端子 → 充電IC(BQ25101) → LDO → 3V3 | BAT端子は使えない。3V3ピンへの直接給電なら動く可能性があるが、電源回路への逆流とスリープ時消費電流が懸念 |
| **D** | **電池 → モジュールのVDD 直結** | **○ レギュレータも充電ICも載せない設計にできる。変換ロスゼロ** |

エネループ2本は満充電2.8V→公称2.4V→終止2.0Vで、nRF52840の動作範囲（1.7〜3.6V）に全域が収まる。問題はチップの手前の電源回路であり、A〜Cは「他人が設計した電源回路に想定外の電圧源を横から突っ込む」形になる。**乾電池を要件に据えるならDに一本化される。**

昇圧IC（2.4V→3.3V）でA〜Cを生かす逃げ道はあるが、常時待機電流を食い無線の省電力と相性が悪いため勧めない。Dなら昇圧そのものが不要。

### D（MDBT50Q）のアンテナ設計は、当初評価より容易

キープアウトの実要件はシンプルで、**アンテナの真下と周辺にグランド・配線・電源プレーンを置かない**（多層基板なら該当領域から全レイヤーのベタを抜く）こと。データシートの表現は "No ground pad should be included in the corresponding position of the antenna. The No-Ground-Pad area should be as wide as you can."

失敗リスクを発注前に潰す手段が3つある:

1. **Raytacが無料でレイアウトレビューをしてくれる**。データシートに、レイアウトをPDFで `service@raytac.com` に送ればアンテナ設計要件への適合をチェックする旨が明記されている。JLC3DPのReview Before Paymentと同じ構図で、既に経験済みの進め方
2. **公開リファレンス設計がある**: `siderakb/mdbt-micro`（MDBT50Q使用のnRFMicro/ProMicro互換ボード）、ErgoSNM（MDBT50Q使用のキーボード）、Skean（E73 nRF52833の完全無線分割キーボード）。アンテナ周辺のレイアウトを実績のある設計から写せる
3. **この構成は干渉源から離しやすい**（下記）

### 本構成での電波干渉の評価

| 干渉源 | 評価 |
|---|---|
| 乾電池（エネループ単3×2）＝金属の塊 | **回避可能**。案Bは電池を後端配置のため、MCUを前端に置けば最も離れる |
| Magic Trackpad＝アルミ筐体が中央にある | **回避可能**。左右それぞれのMCUを**外周側**に置きアンテナを外に向ければ最も遠くなる |
| 3Dプリント樹脂ケース | 問題なし（電波を通す）。ただし薄型化で**金属補強板を入れる場合はアンテナ付近を避ける** |

**「MCUを外周側・前寄り、電池を後端」**という配置ひとつで2つの干渉源から同時に離れる。USB-Cポートも外側に来るが、充電・書き込み用なので支障ない。

**残る懸念は左右間通信（central ⇄ peripheral）が中央のアルミ板で遮られないか**。ただし①BLE 2.4GHzは回折・反射し距離160mmは近すぎるほど近い（到達距離は10m級）②先行例のNakaniwaが製品として成立している ③**ドングル構成にすれば左右がそれぞれドングルと通信する形になり、この問題自体が消える**（ビルド検証済み）。

### → D（MDBT50Q-1MV2 直付け）に決定（2026-08-03）

**乾電池要件を確定したことによる一本化。** 上記「決定的な論点：乾電池と充電回路の衝突」の通り、充電回路を載せない選択ができるのはDだけであり、電池直結でレギュレータも不要になる。

決定を後押しした事実:

- Dのアンテナ設計・ボード定義自作のハードルが、当初評価より明確に低いと分かった（Raytacの無料レビュー・公開リファレンス設計・`akdk_bt1` のdtsがテンプレートに使える）
- **Dは薄型化にも最有利**（約2mm。A=約6mm、B/C=約3.5mm）。乾電池直結でレギュレータと充電ICが不要になり部品点数も減る
- 価格差は全体の1〜2%で判断材料にならない
- フルスクラッチ方針（2026-08-02決定）と整合する

**保留**: C（XIAO Plus）の技適確認は、Dに決めたことで不要になった。Dが行き詰まった場合の代替として調べる価値は残る。

**残る作業**（着手時に潰す）:

- Raytacへのレイアウトレビュー依頼（PCB発注前・必須）
- リファレンス設計（`siderakb/mdbt-micro` 等）のアンテナ周辺レイアウトの参照
- `akdk_bt1` をテンプレートにしたZMKボード定義の作成
- 電池電圧測定（分圧抵抗）とZMK電池残量レポートの校正 — 乾電池は放電カーブがLi-Poと違うため、そのままでは残量表示が正しくない

### ウォッチ: XELBO — 乾電池1本駆動のXIAOサイズ互換ボード（開発中、2026-08-07記録）

せきごん氏（@_gonnoc）が開発中の「XELBO」（[発表ツイート](https://x.com/_gonnoc/status/2084975175347613941)、rev.0）。**乾電池1本＋昇圧一体・XIAOサイズ・コンスルー対応**。裏面シルクに「Do NOT connect LiPo」とあり、A〜Cを消した「乾電池と充電回路の衝突」問題を既製ボードのまま回避できる初の選択肢になりうる。

**販売されたらDの決定を一度再評価する。** 論点:

- **XELBOが勝る点**: 電池1本で済む（単4×1本分のスペースが浮く）／コンスルーで実装ミス＝PCB再発注のリスクが消える／XIAOフットプリントのPCBにすれば**手持ちの未使用XIAO nRF52840×3個で先行検証→XELBOに差し替え**という段階的な進め方ができる（p01のXIAOフットプリント実例も流用可）
- **Dが勝る点**: 薄さ（直付け約2mm vs コンスルー実装で7〜10mm級）
- **未確認事項**: 搭載モジュールの技適／昇圧回路のスリープ時待機電流（キーボードは待機電流が電池寿命を支配する）／価格・入手性・頒布時期

2026-08-07時点でWeb上に情報なし（ツイートのみ）。

## キーレイアウト：p02の split-us60pct をほぼそのまま使う（2026-08-03決定）

実データは `boards/p02-auto-kdk/split-us60pct.json`（Auto-KDK形式）。フルスクラッチのPCBを起こす際も、この配置を正とする。

**構成**（jsonから確認した実値）:

- `switchType: choc2-19`（Choc V2・19mmピッチ）、`isSplit: true`、`minStabilizer: 2`
- 左手 5行×6列（29キー） / 右手 5行×9列（35キー） = **計64キー**（US 60%相当）
- 幅広キーの内訳: 左手 1.25u / 1.5u / 1.75u / 2u / 2.25u が各1、右手 1.25u / 1.5u / 2u / 2.25u が各1
  - **2u以上は左右あわせて4箇所**（左2u・左2.25u・右2u・右2.25u）。これが「スタビなし幅広キーの実用性」検証の対象そのもの

**MDBT50Q採用によりピン制約が消えた**ため、Auto-KDK時代の「無線18ピン上限・トラックボール使用側は実質14ピンで追加不可」という縛りは無関係になった。キーの追加・分割は自由に決められる。

### トラックボール廃止による変更点

p02では右手のみにトラックボールを配置していた（`variant: thumb-25`、`x: 2.5, y: 4.875, a: 180`、2u×2u相当の占有）。ポインティングをMagic Trackpadに移したことで、**右手の親指クラスタ付近に2u×2uのスペースが空く**。

選択肢は2つで、設計時に決める:

1. **空いた場所にキーを追加する**（ピン制約がないため自由）
2. **ケースを詰めて右手を小さくする** — 左右の外形が揃い、中央トラックパッドとの見た目の対称性が上がる可能性がある

なお、右手だけトラックボール分の面積を持っていたため、**現状の左右ケースは非対称**。中央にトラックパッドを置く構成では左右対称のほうが収まりが良い可能性があり、2を選ぶ動機になる。

### 帰結：YUZUキーキャップが流用できる

レイアウトを維持するため、**p02用に発注したYUZUキーキャップ（`boards/p02-auto-kdk/yuzu-design.json`）がp03でそのまま使える**。以前「p03のキー数次第で作り直し（$64〜80）」と書いた懸念は解消した。Choc V2はMXステムで、キーキャップはスイッチが同じである限り引き継げる。

### ✅ スタビなし検証は合格、レイアウト確定（2026-08-04）

**スタビなし幅広キー（2u/2.25u × 4箇所）の実用性検証は完了。** YUZUキーキャップ到着後、p02実機にサンプル軸＋キーキャップを挿して打鍵し、**問題なし・実用に耐える**と判断した。

- レイアウトは現状（split-us60pct流用）のまま**確定**。キーキャップもそのまま使える
- ~~耐えない場合は2u/2.25uを1.5u以下に分割、キーキャップ再発注~~ この分岐は消滅

残る作業は **本番スイッチ Islet 64個＋予備の発注**（軸は同日の打ち比べで Pink Island から Islet に変更。「スイッチ」セクション参照）。

## 複数Mac運用とデバイス切り替え（方針決定 2026-08-03、実機検証は未実施）

**Mac 3台（自分のMacBook / 案件支給MacBook / 導入予定のmac mini）を1組の入力デバイスで扱う**という要件が新たに判明した。ここに、中央トラックパッド構成に固有の問題がある。

**Magic Trackpadは独立したBLEデバイスなので、キーボードと連動して切り替わらない。**

- キーボード（ZMK）は `BT_SEL 0-4` で5台まで一発切り替えできる（p02のキーマップに実装済み）
- Magic Trackpadには切り替えボタンがなく、**macOSのBluetooth設定から手動で繋ぎ直すしかない**
- 結果、「キーボードはmac miniに、トラックパッドは案件MacBookに繋がったまま」という状態が日常的に起きる
- **一体型ケースにすると見た目は1つのデバイスなのに、中身は独立した2デバイス**というギャップがここで露出する

これは「Magic Trackpadを使う＝ZMK側は一切関与しない」という利点（ドライバ・電圧・基板実装のハードルが消える）の裏返しで、トレードオフとして受け入れた構造から出てくる問題。

### 解決方針：blueutil + ホットキー + ZMKマクロによるソフトウェア切り替え（本命 2026-08-03）

**成立を確認した前提2つ:**

- **Magic Trackpadは複数のMacとペアリング情報を保持できる**（同時接続は1台のみ）。切り替えのたびに再ペアリングする必要がなく、接続/切断を叩くだけで切り替わる。※「1ホストしか記憶しない」であればこの方針は不成立だったため、実機入手後に最初に確認する項目にする
- **`blueutil` でデバイスアドレス指定の接続/切断ができる**（`blueutil --connect <addr>` / `--disconnect <addr>` / `--paired` でアドレス取得）。Homebrewで入る単一バイナリ

**構成:**

1. Mac 3台に `blueutil` と「トラックパッドを自分に接続するスクリプト」を置く
2. Hammerspoon か Karabiner でホットキーに割り当てる
3. キーボードを `BT_SEL n` で切り替え → 切り替え先Macでホットキーを押す → トラックパッドがそのMacに来る
4. さらに **ZMKのマクロで1キーに統合できる**: `&bt BT_SEL n` → `&macro_wait_time`（BLE再接続を待つ）→ ホットキー送出。**キー1つでキーボードとトラックパッドが揃って移動する**という理想形になる

常駐エージェントの自作すら不要で、実質「スクリプト1本＋ホットキー登録」で済む。

**クリア済みの前提（2026-08-03 確認）:**

- ✅ **案件支給MacBookにツールを置ける**（MDM制限は問題にならない）
- ✅ **切り替え先Macがスリープ中は動かない**問題は許容できる

**残るリスクと対処:**

- Magic Trackpadは「近くにある最初のペアリング済みMac」に繋がる挙動があるため、どこにも接続していない状態から復帰するとき意図しないMacに奪われる可能性がある。各Macのスクリプトに「非アクティブ時は掴まない／掴んだら離す」ロジックを持たせて対処する
- macOS 12以降のBluetooth TCC権限のプロンプト挙動は実機で確認する

**この方針がケース設計に与える帰結（重要）:**

- **トラックパッドを有線USB-Cで運用する必要がなくなる → ケース内のUSB-Cケーブル取り回しの設計が不要**になる。必要な開口はトラックパッドの充電ポートと電源スイッチの逃げのみ
- **机の上に切替器などの物理デバイスが増えない**。「3個バラバラでごちゃつくのが嫌」というp03の動機と正面から整合する
- キーボードをドングル構成にするかは、この方針とは独立に判断してよい（BLE直結のまま `BT_SEL` で運用できる）

**検証のタイミング**: この方針は**3Dプリンターより先に、Magic Trackpadを買った時点で検証できる**。ケース不要、手持ちのMac 2台で完結する。¥2万の出費だけでp03の運用面リスクが潰せるため、購入後の最優先タスクにする。

### 見送った案（2026-08-03）

- **mac miniをホストに固定**して入力デバイスは常時mac miniに接続、他Macへは画面共有で入る。案件作業の常用に耐えるか不明なため見送り
- **Universal Control**: 同一Apple IDが必須のため、案件支給MacBookでは使えない公算が高い（管理プロファイル）
- **トラックパッドを有線USB-Cで運用 ＋ キーボードをドングル構成**にし、ケーブル1本とドングル1個の挿し替え（またはUSB切替器でワンボタン化）で両方同時に切り替える。ソフトウェア切り替えが成立するなら、机上に物が増えるこの案を採る理由がない。**ソフト案が実機検証で崩れた場合のフォールバックとして残す**（その場合はケース内のケーブル取り回しの設計が必要になる）
  - なお、ドングル構成自体はビルド検証済み（zmk-config-split-us60pctのdongleブランチ、2026-07-15）なので、フォールバックに倒してもファームウェア側の追加ハードルはない

## 完成版の薄型化・電源方式（検討メモ、未決定 2026-07-29）

p02実物のケースが想定よりゴツかった（高さがある）ことを受けた、完成版フルスクラッチ設計に向けた検討メモ。判断はp02を組んで運用してから。

- 高さの内訳: 「チルト＋テント」と「PCB下の部品スタック」が主因。スタックはコンスルー2.5mm＋コントローラ基板1.6mm＋モジュール約2mm≒約6mmと、バッテリー5mm厚（DTP502535）の同居
- Auto-KDK枠内での調整余地（ケース再生成＋再印刷のみで可能）: チルト5°→4.1°（ツールの下限、後端約-2.3mm）、テント4°→0°（片側約-10mm）、底面3mm→1.8mm（-1.2mm）。テント0°はMacBook近似とも整合するが、要否はp02の打鍵で体感してから
- **コントローラ直付け化**（無線モジュールをキーPCBに直接実装、コンスルー廃止）: 単体では約1mmしか薄くならない（律速がバッテリー5mmに移るため）。薄型バッテリーや配置変更とセットで2〜4mm。副次メリット: PCBA工場実装化・のぎけす屋供給依存の解消・コンスルー接触不良の根絶・1枚あたり¥2,000前後安い・USB/アンテナ配置の自由。デメリット: 充電IC等の周辺回路を自作に戻す・アンテナキープアウト失敗時はPCB再発注・修理性低下・ZMKボード定義の自作。技適はモジュール（Raytac MDBT50Q系等）の認証でカバー
- **電源方式：案B（乾電池・エネループ単4×2）に決定（2026-08-03）**。案Aは案Bが機構的に成立しなかった場合の代替として残す
  - **要件の性質**: 当初は薄型化の手段として案A/案Bを対等に並べていたが、Nuioを手放した理由のひとつが「充電の管理が面倒」という実運用の一次要件だったため格上げした。さらに実態を確認すると、**Nuioは1ヶ月に1回の充電で足りていたのに、残量を気にするのが嫌で前倒しでこまめに充電していた**。つまり**問題は充電回数ではなく「残量を気にする認知負荷」**であり、乾電池の本質的な利点は容量ではなく**切れたときの復旧が30秒で終わること**（予備を置いておけば、事前に気にする理由が原理的に消える）。この理解により、容量の絶対値の重要度は下がる
  - ⚠️ **Magic Trackpadは充電式なので「充電を一切気にしない」は達成できない**。ただし気にする対象が3つ（キーボード左右＋トラックパッド）から1つに減る
  - **単3ではなく単4×2を選択（2026-08-03）**。本人にこだわりがないため、容量より厚みを取る判断:

| | 直径（＝ケース厚みを直接決める） | 容量 | 重さ（2本） |
|---|---|---|---|
| 単3×2 | 14.5mm | 約2000mAh | 約54g |
| **単4×2（採用）** | **10.5mm** | 約750mAh | 約26g |

  - 決め手は**単4の10.5mmがMagic Trackpadの最厚部10.9mmとほぼ一致する**こと。これにより「トラックパッドと厚みを揃える」が努力目標から現実的な目標に変わる。容量750mAhも現行のDTP502535（約400mAh）の約2倍で、1ヶ月持っていた実績の2倍に相当。重さも半減するため「据え置き用途につき許容」という妥協が不要になる。エネループは単3も単4も1.2Vで、直列2本＝2.4Vは変わらない
  - 未検討: 電池ボックスを既製ホルダー（単4×2、¥100前後・接点設計不要）にするか、電池を直接抱えて金属接点だけ埋め込む自作にするか。薄型化を狙うなら後者だが、機構設計の手間と引き換え。設計着手時に決める
  - 案A: Li-Po薄型化（4mm厚の402535系300mAh前後）。現行の延長で最小変更。劣化懸念はPHコネクタ交換式（¥1,000前後で挿し替え）で実運用上は緩和されている
  - 案B（採用）: 乾電池（エネループ）を後端配置。キー面から電池が消えて前端8〜9mm級まで攻められ、後端の膨らみはチルト土手を兼ねる。Apple Wireless Keyboard A1314（単3×2の円筒＝足）が造形の前例。容量は単4×2=750mAh/単3×2=約2000mAhで現行の2〜5倍、充電回路不要・劣化と無縁。課題: トラックボールセンサーの電圧レール・重さ（単3×2で約50g増、据え置き用途につき許容と判断 2026-07-29）・エネループ運用前提（アルカリは液漏れリスク）・電池ボックスの機構設計（蓋・接点）
    - センサー電圧の調査結果（2026-07-29）: PAW3222の同族PAW3212のデータシートでは結線により1.7〜2.1V/2.1〜3.6Vの2構成があり、チップ自体は2.4V対応可能。のぎけす屋モジュール（sekigon-gonnoc/small-mouse-sensor-module）の公称は3.3V供給で回路図非公開のため、2.4V直結可否は未確定。確認手段: ①手元の現物に2.4Vを与えて実験（最確実）②作者にBOOTH等で質問 ③不可なら小型昇圧ICでセンサーのみ3.3V化（負荷0.27mAで影響は誤差レベル）。エネループ2本は満充電2.8V→終止2.0VでHigh Segment下限2.1Vとほぼ一致し、直結ならほぼ全容量を使える見込み
- **アルミケース**: 薄さへの寄与は小さい（肉厚分1.5〜2mmのみ、内部スタックは不変）。フルアルミはBluetooth遮蔽が問題で、樹脂窓かボトム樹脂が前提。スナップ→ネジ化の再設計必須、一点物4パーツで$400〜800級。折衷案はMJFナイロン（質感）やボトムプレートのみアルミ（重量感・剛性）
- **リポのコネクタ極性は統一されていない（2026-08-02に実地で判明）**: PHコネクタ（JST PH 2.0mm）には極性の業界標準がなく、セルのメーカーごとに赤黒の圧着位置が違う。p02で買ったDTP502535(PHR)はAuto-KDKコントローラと極性が逆で、そのままでは挿せなかった。回避策は①購入前に商品ページの写真で極性を確認 ②「セル単体＋コネクタ付きケーブル」を別々に買って自分で結線。**案Bの乾電池構成ではこの問題は原理的に起きない**（電池ホルダーは+側バネ/−側平板で極性が物理的に固定され、ホルダーからコネクタまでの配線も自分で作るため）。案Aの薄型リポを選ぶ場合は購入前の極性確認を手順に入れる
- p02運用で測ってから決めること: テント要否、電池持ちの実測（ZMKのBLE電池残量通知で記録）、質感の不満点の特定（軽さ・表面・たわみのどれか）

## キーキャップ：YUZU Custom Keycaps（PFFプロファイル）を本命に

- 旧方針（Choc v1の印字ありキャップは市販品が少ない→フェーズ1は印字なしMBK＋3Dプリント自作で割り切り、印字は後で検討）は、Choc V2化＋YUZUで課題ごと解消したため覆した（2026-07-15）
- YUZU Custom Keycaps（https://yuzukeycaps.com/ 、製造はKeyreative）で、自分のレイアウト・印字あり・1.5mm厚PBT・昇華印刷のキャップを少量注文できる。1キー$0.75〜（64キーで$48〜＋送料）、納期20〜30日
- プロファイルは**PFF**（matt3o設計、高さ5mm、Choc V2/Gateron LP専用のロープロ、全段同形）を本命にする。フラットでMacBook近似の目的に合い、Cherry彫刻より背が低い。PFFはChoc v1非対応
- Auto-KDKの「キーキャップ(YUZU)」連携でレイアウトを持ち込める。キーごとのRowIndex（R1〜R4=Cherry段指定、R0=KAM）はCherry/KAM用で、PFFは全段同形のため実質不要（PFF注文時の連携挙動はYUZU画面で要確認）
- 発送前の製造確認写真は必ずチェックする（印字位置ミスが稀にあるとのレビューあり）
- Auto-KDK生成のyuzu-set.jsonをYUZUに読み込み、プロファイルをPFFに切り替えて確認済み（2026-07-15）: 必要な全キー幅（1.25u/1.5u/1.75u/2u/2.25u）とhomingキーがPFFで揃う。64キーで$63.90（KAMと同額）。注文はPCB等の納期に合わせて後日でよい
- デザイン確定（2026-07-15、boards/p02-auto-kdk/yuzu-design.json にエクスポート保存・YUZUアカウントにもSave済み）:
  - ベース色 GR1（RAL 000 15 00 ニアブラック）×印字色 GR2（White）の全キー単色。MacBook黒キーボード再現
  - フォントはNoto Sans、英字は大文字・中央配置（X:0 CENTER / Y:光学補正で微調整）。数字段は記号+数字の2段表記
  - アイコンはFramework7 Icons（SF Symbols風）で統一: 矢印はarrowtriangle系のSize 20、修飾キーは⇧⌥⌘⌫⏎^グリフ、EnterにAppleロゴ（自分用のため商標は問題なし）
  - YUZUのレイヤー編集の注意: 使わないテキストレイヤーは削除不可のためLabelを空にして無効化する。テキストサイズとアイコンサイズは別管理
- 3Dプリント自作（YUZUのSTLではなく自前モデリング）は、造形自由度が必要になった場合の予備手段に格下げ

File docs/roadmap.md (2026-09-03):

# ロードマップ

最終形を一度で作らず、試作ごとに検証対象を絞る。
試作ディレクトリは先に作らず、着手する時点で追加する。

設計判断の理由は `docs/decisions.md`、各試作の作業記録は `boards/*/build-log.md` を参照。

## 現在の状態（2026-08-07）

**p01・p02は未完成のまま保留**とし、**p03（中央トラックパッド統合・フルスクラッチ）に進む**。

保留は放置ではなく判断として記録済み。理由の要約は下記、詳細は各build-logの「保留」節と `docs/decisions.md` の「p01・p02は未完成のまま保留にする」を参照。

**プロジェクト自体を一時休止中（2026-08-07〜）**。他プロジェクトが忙しいため。再開の目安は**XELBO（乾電池1本駆動のXIAOサイズ互換ボード、`docs/decisions.md` の「ウォッチ: XELBO」参照）の販売開始**。再開時はまずMCU選択（D: MDBT50Q直付け vs XELBO/XIAOフットプリント）を再評価してからフェーズ0に着手する。

## p01-simple-split（保留）

目的だったZMK・左右分割・Choc v1・親指キー・ソケットはんだ・JLCPCB発注（PCB＋部分PCBA）の学習は**すべて達成済み**。

残作業はXIAO 2個のdirect mountはんだ付けのみ（追加出費ゼロ・1〜2時間）だが、完成させない:

- p03では自作PCBにMCUを載せるため、既製ボードを他人のPCBに直付けする経験の転用価値が薄い
- Corne系42キーは日常運用に投入できず、「1週間試す」ができない
- Choc v1 Red・MBKキーキャップはChoc V2（MXステム）と非互換で部品も引き継げない

**残る資産**: XIAO nRF52840 が3個とも未使用のまま / `tools/keytest.html` / Chocソケットの余り / PCBはXIAOフットプリントの実例として参照可。

## p02-auto-kdk（保留）

**到達点はPCBの疎通確認まで。** 左右PCBのChocソケットはんだ付け（64箇所）を終え、ピンセットでソケットを短絡する方式で全数の導通・入力を確認した（右手34/35キー・`k` のみ断線、左手29/29キー）。ファーム書き込み・左右のBLE接続・central経由のHID出力も確認済み。

**ただしスイッチ・キーキャップ・ケースは未装着、バッテリーも未接続（USB給電）で、打鍵できる状態ではない。** 残作業に対して得られる設計入力が見合わないため完成させない。

- p03に必要な実測値（左右間隔・奥行きの揃え方・トラックパッド面との高さ差）は、**結局p03の実物を3Dプリントして手を乗せないと決まらない**
- バッテリー極性の再工作は一度失敗済み、トラックボールはモジュール再購入（¥4,500）が必要、本番スイッチ64個は¥5,000

**ただし2つの役割が残る:**

1. **ケース実物は、p03の配置検討モックアップ**として使える（左右間隔・高さ・角度を実寸で再現できる唯一の現物）
2. **スタビなし幅広キーの検証台**。これはp02でしか分からず、かつp03のレイアウト確定に必須（下記）

## p03: 中央トラックパッド統合・フルスクラッチ（次に着手）

目的: Magic Trackpadを左右分割キーボードの中央に統合し、**自作PCB＋自作ケース**で「机の上が1つにまとまる」構成を実現する。

ディレクトリ名は着手時に決める。

### 決まっていること（2026-08-03時点）

| 項目 | 決定 |
|---|---|
| ポインティング | **Apple Magic Trackpad（USB-C・ブラック／感圧式）を左右の中央にはめ込む**。BLEでMacに直結する独立デバイスのため、ZMK側は一切関与しない |
| MCU | **Raytac MDBT50Q-1MV2 直付け**（¥1,185〜1,265／技適済み／約2mmで最薄） |
| 電源 | **エネループ単4×2（2.4V）を直結**。レギュレータ・充電IC不要 |
| キーレイアウト | **p02の `split-us60pct` をほぼそのまま**（Choc V2 19mmピッチ・64キー・左29/右35） |
| スイッチ | Kailh Deep Sea Silent MINI **Islet**（43gf 静音リニア）。~~Pink Island（35gf）~~ からキーキャップ込みの打ち比べで変更（2026-08-04） |
| キーキャップ | **YUZU（PFFプロファイル）をp02から流用**。再発注不要 |
| ケース | **自作・3Dプリント内製**（Bambu Lab X2D） |
| 複数Mac切り替え | **blueutil + ホットキー + ZMKマクロ**のソフトウェア方式 |
| ファームウェア | ZMK。ボード定義は `akdk_bt1` の生成物をテンプレートに自作 |

### 設計順序の原則：反復の安いものから固める

**ケース（3Dプリントで何度でも刷り直せる）を先に固め、PCB（1回$100〜200＋納期2〜3週間）を後に回す。**

ケースとPCBは相互依存する（PCBの外形・ネジ穴・コネクタ位置がケースを決め、ケースの厚みと配置がPCBを縛る）が、失敗コストが2桁違うので、先に安いほうで探索して寸法を確定させる。

### 作業順序

#### フェーズ0: 購入

- [ ] Bambu Lab X2D 単体 ¥126,000（AMSは使わないためComboは不要）
- [x] **Apple Magic Trackpad（USB-C）ブラック（Multi-Touch対応）¥21,800 — 購入済み 2026-08-27**（Apple Store。感圧式の現行モデル。初代の物理ヒンジ式は不可）

#### フェーズ1: 到着後すぐ潰せる検証（ケース設計に入る前）

- [ ] **複数Mac切り替えの実機検証**。最初に確認するのは「**Magic Trackpadが複数Macのペアリングを保持するか**」— ここが崩れると切り替え方針ごと崩れる
  - [ ] `blueutil --paired` でアドレス取得 → `--connect` / `--disconnect` の動作確認
  - [ ] Mac 3台へのスクリプト配置とホットキー登録
  - [ ] Bluetooth TCC権限の挙動確認
  - [ ] 「近接Macに奪われる」挙動への対処（非アクティブ時は掴まない／掴んだら離す）
- [ ] **Magic Trackpadの実測**（外形・厚み・角R・背面のポートとスイッチ位置）と断面スケッチ
- [ ] **公差テストピースの印刷**（トラックパッドの角Rと厚みの小片・爪のスナップ1箇所・ネジボス1個）。CAD習熟と機械の癖（実寸のXYズレ）の把握を同時に進める
- [x] **スタビなし幅広キーの検証**（キーキャップ到着後・p02実機＋サンプル軸の余りで実施）→ **合格・レイアウト確定（2026-08-04）**

#### フェーズ2: ケース設計（3Dプリントで反復）

一体化の度合いは安いイテレーションから上げる（`docs/decisions.md`「ケースの一体化は段階的に上げる」参照）。

- [ ] **単独トレイ**（トラックパッドの台のみ）を刷って、左右間隔・角度・高さを実物で追い込む
  - p02のケース実物を左右に置いて配置を再現する
  - トラックパッド面はキートップとツライチ〜2、3mm低めが定番。シム／調整脚で±3mm動かせるようにして実物で追い込む
- [ ] 気に入った配置を実測 → 左右間隔・角度・高さのパラメータ確定
- [ ] **耳付き中央ユニット** → **フルベース板**（500mm超は3分割印刷＋結合）→ **完全一体型**へ段階的に上げる
- [ ] 電池ボックスの機構設計（単4×2。既製ホルダーか、電池直抱え＋金属接点の自作か）
- [ ] トラックパッドの充電ポート・電源スイッチの逃げ、取り出し用の指掛かり穴

#### フェーズ3: PCB設計（ケースの寸法確定後）

- [ ] 回路設計: MDBT50Q + 乾電池直結 + USB-C + ESD保護 + リセット/電源スイッチ + 電池電圧分圧
- [ ] アートワーク: **アンテナのキープアウト厳守**。MCUは外周側・前寄り、電池は後端に配置して干渉源から離す
  - リファレンス設計を参照: `siderakb/mdbt-micro` / ErgoSNM / Skean
- [ ] **Raytacへレイアウトレビューを依頼**（PDFを `service@raytac.com` へ・無料・発注前必須）
- [ ] JLCPCBへ発注（PCB + 部分PCBA。ダイオード実装は工場に任せる）

#### フェーズ4: ファームウェア・組み立て

- [ ] ZMKボード定義の作成（`boards/p02-auto-kdk/generated/boards/arm/akdk_bt1/` をテンプレートに）
- [ ] **乾電池の放電カーブに合わせたZMK電池残量レポートの校正**（Li-Poとカーブが違うため、そのままでは残量表示が正しくない）
- [ ] キーマップ・コンボの移植（p02の資産を流用。トラックパッド採用でジェスチャ代替コンボは不要）
- [ ] 本番スイッチ Islet 64個＋予備を発注 ← ~~レイアウト確定後~~ **レイアウト確定済み（2026-08-04）、発注可能**
- [ ] Chocソケットのはんだ付け → 組み立て → 実機確認

### 未決事項

- **トラックボール廃止で空いた右手の2u×2u**をどうするか（キーを追加する / ケースを詰めて左右対称にする）
- **奥行きの揃え方**（トラックパッド114.9mm vs p02ケース147.8mm の33mm差を、手前／奥／中央のどこで揃えるか）
- **Auto-KDKコントローラのライセンス解釈**（自作PCBへの流用可否。Dに決めたため当面不要だが、フォールバック時に必要）
- **XIAO Plus の技適**（同上。Dが行き詰まった場合の代替として）

## target

**p03がそのままtargetになる可能性が高い。**

旧targetの定義（Auto-KDK専用無線ボード・PAW3222トラックボール・BLEドングル前提）は、2026-08-02のフルスクラッチ移行で失効した。`docs/target.md` も旧方針として明記済み。

p03で満足すればそれをtargetとしてよい。フェーズ2（アルミ削り出し等の素材変更）は、p03を実際に運用してから検討する。

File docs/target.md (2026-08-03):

# 最終形の仕様まとめ

> ⚠️ **このファイルは 2026-06-30 時点の旧方針**（Ergogen + KiCad / Choc v1 / PMW3610トラックボール / エンコーダー / XIAO nRF52840 Plus 前提）で、以降更新していない。2026-07-15 のAuto-KDK採用と 2026-08-02 のフルスクラッチ決定で大半が覆っている。
> **現行の方針は `docs/decisions.md` が正**。このファイルは下記KLEレイアウト（キー数・キー順・ラベルの基準）の参照元として残す。

このファイルは `target/` で目指す最終統合版の仕様を記録する。
各試作機の仕様は `boards/pXX-*/README.md` に分ける。

## レイアウト

| 項目 | 内容 |
| ---- | --- |
| 分割 | 左右分割、ロースタッガード |
| 左手 | 6列×5行 + EVQWGD001エンコーダー（escの左） |
| 右手 | 7列×5行 + PMW3610トラックボール（親指エリア） |
| 配列 | US配列、FNキーなし、英数・かなキーなし |

KLEレイアウトはキー数・キー順・ラベルの基準として扱う。Ergogen上の物理座標、列スタッガー、親指キー位置、トラックボール位置は1:1印刷プロトタイプで確認しながら調整する。

## KLEレイアウト

### 左手側

```json
[{a:5,f:5},"`\n~","!\n1","@\n2","#\n3","$\n4","%\n5"],
[{x:0.5,a:7,f:5},"tab","Q","W","E","R","T"],
[{x:0.75,a:4,f:2},"ctrl",{a:7,f:5},"A","S","D","F","G"],
[{x:1.25,a:4,f:2},"shift",{a:7,f:5},"Z","X","C","V","B"],
[{x:1.5,a:4,f:2},"esc","caps","opt","⌘","space"]
```

### 右手側

```json
[{a:5,f:5},"^\n6","&\n7","*\n8","(\n9",")\n0","\"\n'","+\n="],
[{x:0.5,a:7,f:5},"Y","U","I","O","P",{a:5},"{\n[","}\n]"],
[{x:0.75,a:7,f:5},"H","J","K","L",{a:4,f:2,w:1.5},"Enter","_\n-",{a:5,f:5},":\n;"],
[{x:1.25,a:7,f:5},"N","M","<\n,",">\n.","?\n/","↑","|\n\\"],
[{x:1.5,a:4,f:2},"space","⌘","opt",{x:0.75,a:7},"←","↓","→"]
```

## 入力デバイス

| 項目 | 内容 |
| --- | --- |
| スイッチ | Kailh Choc v1 Red（リニア） |
| トラックボールセンサー | PMW3610 |
| トラックボール基板 | SideraKB PMW3610 PCB Rev 2.x系互換 |
| トラックボール径 | 34mm |
| トラックボールクリック | Auto Mouseレイヤー（J・Kキー） |
| スクロール | ボタン押しながらボール転がす |
| エンコーダー | EVQWGD001（左手のみ）レイヤー0=音量、レイヤー1=輝度 |

## 接続・ファームウェア

| 項目 | 内容 |
| --- | --- |
| ファームウェア | ZMK |
| 左右間通信 | BLE |
| PCとの接続 | BLEドングル（USB挿しっぱ） |
| MCU | XIAO nRF52840 Plus候補 × 3（左右 + ドングル） |

XIAO nRF52840 Plusは、トラックボール・エンコーダー・キーmatrixで無印XIAOのGPIOが足りない場合の候補とする。既存の無印XIAO前提シールドに載せても追加GPIOは使えないため、Plus採用時は追加キャステレーションパッドまで配線したPCBを設計する。

## PCB・ケース

| 項目 | 内容 |
| --- | --- |
| PCB設計フロー | Ergogen → FreeRouting → KiCad最終調整 |
| Ergogen初期成果物 | キー配置 + 外形 + 1:1印刷用アウトライン |
| トラックボール領域  | 34mm円 + 46mm keepout円 + 23.5mm×31.5mm基板矩形 |
| PCB発注 | JLCPCB |
| ケース（フェーズ1） | 3Dプリント（PLA/PETG）、DMM.make or JLCPCB発注 |

## キーキャップ

| 項目 | 内容 |
| --- | --- |
| 1Uキー | MBK市販品（印字なし、フェーズ1） |
| Enterキー（1.5U） | 3Dプリント自作（Choc v1ステム）  |

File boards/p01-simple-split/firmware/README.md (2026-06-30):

# firmware

p01-simple-split用のZMK config作業場所。

## 現在の状態

- `zmk-config/` は `wintinue/zmk-corne` をベースにしたコピー
- 取り込み元commit: `0236c3a9f466411806be85f202e3c509db495592`
- 取り込み元commit日付: 2026-05-16
- `zmk-config/build.yaml` のboard名を `xiao_ble//zmk` に更新済み
- root workflow `.github/workflows/p01-zmk-build.yml` で `chipper_left` / `chipper_right` のUF2をビルドする
- GitHub Actions run `28447236060` で左右のUF2生成を確認済み

## 次にやること

- 実機入手後、生成済みUF2を左右のXIAO nRF52840へ書き込んで起動確認する

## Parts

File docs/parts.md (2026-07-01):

# 部品メモ

確定部品、候補部品、試作ごとの差分を記録する。

## 確定寄り

| 種別 | 部品 | 用途 | メモ |
| ---- | ---- | ---- | ---- |
| PCB | JonMuller `corne-choc-xiao` | p01 | ハードウェア正本。JLCPCBへPCB 5枚 + bottom side部分PCBA 5枚を発注済み |
| スイッチ | Kailh Choc v1 Red | 全試作共通 | ロープロファイル、リニア |
| MCU | Seeed Studio XIAO nRF52840 | p01 | 既存Corne Xiao系シールドとの互換性を優先 |
| トラックボールセンサー | PMW3610 | 後続試作、target | ZMK対応を前提 |
| エンコーダー | EVQWGD001 | 後続試作、target | 左手側のみで検証 |

## 未確定

| 種別 | 候補 | 確認したいこと |
| ---- | ---- | ---- |
| MCU | Seeed Studio XIAO nRF52840 Plus | target候補。追加GPIOが必要か、Plus用パッドをPCBで拾うか |
| キーキャップ | MBK / 自作 | 打鍵感、親指キー形状、印字方針 |
| ホットスワップソケット | Choc v1対応 | 基板セット同梱の有無 |
| ケース素材 | PLA / PETG / その他 | 強度、精度、手触り |
| バッテリー | 未定 | 容量、厚み、配置 |
| バッテリーコネクタ | JSTなど | 基板側仕様、同梱の有無 |
| 左右接続の物理構成 | 未定 | 電源スイッチ、充電、デバッグしやすさ |

## 注意メモ

- LeducH `corne-choc-xiao` はJonMuller版とGerber/BOM/CPLが同一なので、整理版・ガイド・購入リンクとして参照する
- p01のZMK configはwintinue `zmk-corne` を出発点にし、`chipper_left` / `chipper_right` を使う。current ZMK向けに `xiao_ble//zmk` へ変更し、GitHub Actionsで左右UF2生成確認済み
- Choc標準18x17mmキーキャップ前提。19x19mm系キーキャップは使わない
- 無印XIAO前提の既存シールドにXIAO nRF52840 Plusを載せても、基本14ピン互換部分しか使えない
- Plusの追加GPIOを使うには、追加キャステレーションパッドまで配線したPCBが必要
- `BAT` や `AIN7_BAT` など電源系に見える名前のパッドは、必ず回路図で用途を確認してから配線する

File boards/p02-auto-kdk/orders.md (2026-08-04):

# p02 発注チェックリスト

Auto-KDK README（4.8〜4.11）と調査結果に基づく発注手順。2026-07-15作成。

## 決定済み（デファクト採用でOK）✅

- ✅ **PCBA bottom side**（ダイオード64個を工場実装。2026-07-15決定。p01の部分PCBAと一貫、ケースとは別便になる）
- ✅ **Chocソケットは自分ではんだ付け**（JLCPCBに在庫がなく事前部品送付は割に合わない。実質一択）
- ✅ **PCBは面付け（panelized）版・Different Design=2**（README推奨、安いことが多い）
- ✅ **PCB枚数はデフォルト5枚**（PCBA価格は2枚とほぼ同額。ソケットはんだ失敗や将来の予備になる）
- ~~✅ ケース素材: LEDO 6060 レジン・黒系~~ → **JLC Black Resinに変更**（LEDO 6060は白のみと判明。要検討セクション参照。質感重視のMJFナイロン等はレイアウト確定後のフェーズ2で、の方針は維持）
- ✅ **JLC3DPの商品カテゴリ: プラスチックキーボードエンクロージャ**（README指定）
- ✅ **研磨リマーク記載**（README指定の既知トラブル対策）
- ✅ **フォームは省略**（ガスケットマウント用が主目的。インテグレーテッドでは不要）
- ✅ **コントローラ・トラックボールモジュールはBOOTH（のぎけす屋）**（専用品につき一択）
- ✅ **YUZUキーキャップはデザイン確定済み、注文は納期逆算で後日**

## 要検討（ちゃんと考えて決める）

- [x] **軸（Choc V2のバリアント）: Kailh Deep Sea Silent MINI Islet（43gf 静音リニア）に決定（2026-08-04）**。YUZUキーキャップ到着後、キーキャップ込みで打ち比べたら Islet が最良だった。~~2026-08-02にキーキャップなしの素打鍵で Pink Island（35gf）に決定~~ を再度覆し、2026-07-15の当初本命 Islet に帰着。教訓: **軸の打ち比べはキーキャップを装着してから**（キャップの質量で評価が逆転する）
- [x] **バッテリー: DTP502535(PHR) 400mAh × 2本に決定**（2026-07-15。共立エレショップ https://eleshop.jp/shop/g/gH4H31G/ 。5×25×35mmで上限6×31×52mm内、保護回路内蔵、PHコネクタ付き）
  - 左右同容量のシンプル構成。右手はトラックボールで消費が大きいため、電池持ちに不満が出たら右だけ500〜600mAh級（602540等、保護回路+PH2.0条件）に買い足す
  - **接続前の極性チェック必須**: ボード側シルクの＋/−とバッテリーの赤黒線の並びを目視で突き合わせる。逆ならPHコネクタのコンタクトを抜いて左右入れ替える。確認するまで絶対に挿さない（逆挿しはボード即死）
  - **結果（2026-08-02）: 極性は逆だった。** ボード側は導通チェック（USB-Cシェル＝GNDとPHコネクタ端子の導通）でシルク通りと確認済み。コネクタのツメで決まる挿し方向では赤線が `−` 側に来るため、**そのままでは挿せない**。コンタクト差し替えかはんだ付けでの入れ替えが必要（左手側で確認。左右でコネクタが鏡像配置のため右手側は要再確認）
  - **教訓**: PHコネクタには極性の業界標準がなく、リポのメーカーごとに赤黒の配置が異なる。Auto-KDKのREADMEも極性注意を明記している。次回は①商品ページの写真で極性を確認して買う ②または「セル単体＋コネクタ付きケーブル」を別々に買って自分で結線する（後者なら原理的に問題が起きない）
- [x] **スナップ方向: horizontalのままでOK（確認済み・対応不要）**: リリースノートによると2025/04/26に水平方向がデフォルト化、2025/05/17に**水平方向のみに限定**されており、現行仕様では選択肢自体が存在しない。マニュアルの「Vertical（標準）/Horizontal（FDM向け）」の記述が古いだけだった。STL再生成は不要
- [x] **ケースの色: JLC Black Resin（Black）に決定**（2026-07-16。LEDO 6060はNatural White一色のみと発注画面で判明し前提が崩れたため再検討。黒系3種のうちJLC Black Resinが最安$146.24かつ機械特性最良〔High strength / Excellent toughness、耐熱65°C〕で一択。白LEDO $92.69との差+$53.55は見た目への投資として許容。参考: Black Resin=灰味黒$174.05、Imagine Black=外観向け$192.58）

## A. BOOTH（のぎけす屋）ほかトラックボール部品

> **2026-08-02: p02ではトラックボールを見送り。** センサーモジュールのFFCコネクタのラッチを破損したため。完成版ではトラックパッドを検討する方向で、再購入（¥4,500）はしない。ボール・支持球・FFC・ボンドは未使用のまま保管。ケースのトラックボール穴は開いたままになる。

- [x] 無線コントローラボード 2個セット ¥9,000（コンスルー付属）: https://booth.pm/ja/items/6604431 — **発注済み 2026-07-15 注文番号84437813**
- [x] 14mmマウスセンサーモジュール（モジュール単体）×1 ¥4,500: https://booth.pm/ja/items/6520217 — **発注済み 2026-07-15 注文番号84437813**（FFCコネクタ変換基板はAuto-KDKでは不要と判断して単体を選択）
- [x] 25mmトラックボール球（ブラック）¥1,600: https://booth.pm/ja/items/6457643 — **発注済み 2026-07-15 注文番号84437754**
- [x] セラミック支持球 φ2mm×30個: Amazonで発注済み 2026-07-15（お届け7/19）
- [x] FFCケーブル 0.5mmピッチ・6ピン・150mm・Aタイプ×10本: Amazonで発注済み 2026-07-15（お届け7/27〜8/1）
- [x] 木工用ボンド（コニシ 多用途50g）: Amazonで発注済み 2026-07-15（お届け8/14と遅め。急ぐ場合はCan Doでも買える）
- [ ] マスキングテープ: 近所のCan Doで購入予定（用途は、はんだ養生・ケース嵌合調整なので100均品で十分）
- [x] 爪楊枝: 手持ちあり
- [ ] ビニールテープ: 近所のCan Doで購入予定（バッテリー固定用。README推奨の「不燃性のビニールテープ」＝普通の電気絶縁ビニールテープでOK）

## B. JLCPCB（PCB発注、README 4.8〜4.9）— ✅ 発注完了 2026-07-16

- [x] EasyEDA（Std版）にアカウント作成・ログイン
- [x] Auto-KDKのzipをEasyEDAで開く → 3種の基板（left/right/panelized）を読み込み、プロジェクト「split-us60pct」として保存
- [x] DRC実行 → **DRC Errors 0 / Nets 89/89** 確認（panelized）
- [x] `Tool -> TearDrop` でティアドロップ付与（デフォルト設定）→ 保存
- [x] panelized版で発注。Different Design=2、Panel by Customer、5枚
- [x] PCB Assembly: Economic・Bottom side・5枚。ダイオード1N4148W=C81598（Basic）×320個のみ実装、Chocソケット（C5333465）は「配置しない」
- [x] U1_L/U1_R警告はContinueでスキップ、配置確認で裏面ダイオードを目視確認
- [x] 商品説明「Office Appliance and Accessories → Keyboard」→ 決済完了 **$56.26**（PCB $29.83 + PCBA $23.58 + 送料UPS $8.85 − クーポン$6。PCB prototype: Y3-12985604A）
- [ ] 発注4〜6時間後にOrder Historyの**DFM Analysis**で最終配置を確認
- [ ] JLCPCBからの確認メールが来たら対応（コンスルー穴は「そのまま製造」と回答）

## C. JLC3DP（ケース発注、README 4.10）— 注文提出済み 2026-07-16、レビュー待ち

- [x] `generated/case/` のSTL4ファイル（left/right × top/bottom）をアップロード
- [x] 素材: **JLC Black Resin / Black**、Surface Finish: General Sanding、商品概要「Office Appliance and Accessories → Plastic Keyboard Enclosure」
- [x] Remarkに研磨リマーク記載（"Please do NOT sand/polish off the small snap-fit bosses..."）
- [x] Thin walls detected警告（3ファイル）は想定内として承諾
- [x] 注文提出 **注文番号 W2026071523545461**、合計$154.92（本体$146.24＋送料UPS $8.68）。**Review Before Payment方式: ファイルレビュー承認後に手動で支払い**（自動決済はオフ）
- [ ] **レビュー承認後に支払い**（10分〜4時間/営業時間内。Order Historyで確認。決済画面にクーポン欄があれば$10 OFFを適用）
- [ ] ファイル名横に「!」マークが出たらクリックして「はい」
- [x] レビュー中のメール問い合わせ対応: 実際の問い合わせは薄壁リスクの確認だった（roux@jlcpcb.com、7/17に催促あり）。壁厚 A=0.27/B=0.48/C=0.80/D=0.50/E=0.50mm が推奨0.8mm未満＋反りの一般リスクの承諾確認。発注時に想定内として承諾済みの内容なので「現行ファイルのまま製造でOK（リスク承諾）」と**2026-07-17に返信済み**。※コンスルー穴の質問は来ていない

## D. スイッチ・部品（遊舎工房 / Daily Craft Keyboard / TALPKEYBOARD等）

- [x] Choc V2 軸打ち比べ用サンプル — 発注済み:
  - [x] **Islet（本命・43gf静音リニア）×3**: 遊舎工房 2026-07-15 確認番号HVFFAVQYR
  - [x] Pink Island（35gf静音リニア）×3: 同上
  - [x] Whale（45gf静音タクタイル）5個: TALPKEYBOARDで発注済み 2026-07-15 確認番号K0ML8J8AC ¥750（遊舎工房はばら売り欠品のため）
  - ~~Red（50gf非静音・基準器）~~ 省略。非静音リニアの基準はp01のChoc v1 Redで代用する
- [ ] **本番用スイッチ発注: Kailh Deep Sea Silent MINI Islet を 64個＋予備（計70個推奨）**（~~Pink Island~~ から変更 2026-08-04。遊舎工房の商品名は「Kailh Deep Sea Low Profile Choc V2 サイレントスイッチ 1353 RGB MINI」のIsletバリアント）。遊舎工房で購入予定。手持ちのサンプルIslet 3個を含めても61個不足。**これが全体のクリティカルパス**（届かないとケースを組めない）。レイアウト確定済み（スタビなし検証合格 2026-08-04）のため発注可能
- [x] Kailh Switch Socket **Choc用**（10個入）×7袋=70個: 遊舎工房 2026-07-15 確認番号HVFFAVQYR
- ~~ダイオード 1N4148W~~ PCBAで工場実装するため購入不要
- [x] Li-Poバッテリー: **DTP502535(PHR) 400mAh × 2本**: 共立エレショップで発注済み 2026-07-15 オーダーID EC26071523011383（**届いたら極性チェック**。要検討セクション参照）
- [x] USB Type-Cケーブル: 手持ちあり
- [x] ケース用滑り止め（GRIPLUS 極薄シール スリム ブラック）: Amazonで発注済み 2026-07-15（お届け7/19）

## E. YUZU（キーキャップ、納期20〜30日）— ✅ 発注完了 2026-07-16

- [x] 発注完了 **確認番号 #K0D7MHFD8**、$78.90（本体$63.90＋送料SF Express $15.00）。PFF PBT dye sub 64キー、デザインID 505f17c8-9082-4a2e-84f7-32c37992f9e6
- [ ] 約1週間後に届く**製造確認写真を必ずチェック**（印字位置ミスが稀にある）

## 備考

- 工具は手持ち確認: はんだごて、ペンチ（コントローラのレール折り取り・コンスルー加工用）、ピンセット
- フォーム（README 4.11）はガスケットマウント用が主目的のため、インテグレーテッドの今回は省略でよい（ボトムフォームが欲しくなったら遊舎工房レーザーカットで後日）
- ファームウェアは発注と独立して完成済み（GitHub Actionsビルド通過、ZMK Studio対応）

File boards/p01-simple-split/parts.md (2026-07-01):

# p01 発注・購入チェックリスト

調査日: 2026-07-01

## 結論

p01は `JonMuller/gerbers` の `corne-choc-xiao` を正本にして、JLCPCBでPCBを発注した。

発注方針は **PCB + 部分PCBA**。PCBA対象は公開BOM/CPLに含まれるダイオードとバッテリーコネクタだけに限定し、XIAO、スイッチ、ソケット、キーキャップ、電源スイッチ、バッテリー、ケース類は自分で購入・実装する。

発注後も次は未解消なので、部品購入・組み立て前に確認する。

- `J8` を使うなら、Molex Pico-EZmate 1.2mm系に合うバッテリー/ケーブルを選び、極性を確認する
- XIAO nRF52840はdirect mount前提として扱い、ソケット化しない方針で組み立て手順を確認する
- 電源スイッチはGerber上の `SW23` footprintに合うthrough-hole SPDT slide switchを選ぶ

## JLCPCB発注結果

発注日: 2026-07-01

| 項目 | 値 |
| ---- | ---- |
| 発注方式 | PCB + エコノミックPCBA |
| PCB数量 | 5 |
| PCBA数量 | 5 |
| 組立サイド | bottom side |
| 納品形式 | 面付け済み |
| different designs | 2 |
| PCB色 | green |
| PCB厚 | 1.6mm |
| 表面仕上げ | HASL with lead |
| PCB価格 | `$13.63` |
| PCBA価格 | `$28.29` |
| 商品合計 | `$41.92` |
| 発送予定日 | 2026-07-04 |

発注時に確認済み:

- BOM/CPLアップロード後の検出部品は2種類だけ
- `C2972761` は `D1`-`D21` の `1N4148SOD-323`
- `C505023` は `J8` の `781710002` / Pico-EZmate 1.2mm connector
- 配置previewで `D1`-`D21` が各ダイオードパッド上に載っている
- 配置previewで `J8` が `J8` フットプリント上に載っている
- PCBA remarkは `Assemble BOM/CPL listed parts only: D1-D21 and J8. Bottom side assembly.`

発注後にJLCPCBのDFM/PCBAレビューで確認依頼が来た場合は、承認前に内容を確認する。

## 遊舎工房購入結果

購入日: 2026-07-01

| 項目 | 数量 | 金額 | 状態 | メモ |
| ---- | ----: | ----: | ---- | ---- |
| Kailh Switch Socket - Kailh Choc ロープロファイル用（10個） | 5 | `¥935` | 購入済み | 50個分。Choc v1 hot-swap socket |
| MBK Choc Low-Profile Keycaps - 1U Homing / Black | 2 | `¥330` | 購入済み | 左右ホームポジション用 |
| MBK Choc Low-Profile Keycaps - 1U / Black | 5 | `¥3,850` | 購入済み | 50個分 |
| Kailhロープロファイルスイッチ - Red Pro / 35pcs | 2 | `¥4,620` | 購入済み | 70個分。赤軸完売のためRed Proで進める |

| 項目 | 金額 |
| ---- | ----: |
| 小計 | `¥9,735` |
| 送料 | `¥550` |
| 合計 | `¥10,285` |
| 税 | `¥935` |

Red ProはChoc V1互換のリニアスイッチなのでp01の基板・ソケット・MBKキーキャップに使える。標準赤軸より軽く、誤爆しやすい可能性はあるが、ソケット式なので後から差し替え可能。

## 秋月購入結果

購入日: 2026-07-01

| 項目 | 数量 | 金額 | 状態 | メモ |
| ---- | ----: | ----: | ---- | ---- |
| Seeed XIAO BLE nRF52840 | 3 | `¥5,340` | 購入済み | 型番 `102010448`。左右2個 + direct mount失敗時の予備1個 |

| 項目 | 金額 |
| ---- | ----: |
| 商品金額合計 | `¥5,340` |
| 送料 | `¥550` |
| 注文金額合計 | `¥5,890` |

XIAOは左右で2個必要。今回の秋月購入で3個確保できたため、1個をdirect mount失敗時の予備にできる。

## 固定する製造ファイル

正本:

- Repository: <https://github.com/JonMuller/gerbers/tree/main/corne-choc-xiao>
- Commit: `53fe015c219462c6c3ef0841d53b17c03e8a4749`
- Commit date: 2025-06-21 UTC
- 設計名: `Corne-XIAO Reverso`

使うファイル:

| 用途 | ファイル | SHA-256 | メモ |
| ---- | ---- | ---- | ---- |
| PCB製造 | `GERBER-corne-choc-xiao.zip` | `af17960263833cc1e20b1368b8cdf4c39b5cf607cc2cac8135a3a71178e09e83` | JLCPCBに最初にアップロードする |
| PCBA部品表 | `BOM-corne-choc-xiao.csv` | `eebdda800166a5c882a9f32c51b345c6c670c96b8c82731cb557c70a78ca036b` | ダイオードとバッテリーコネクタのみ |
| PCBA配置 | `CPL-corne-choc-xiao.csv` | `50fbe5af51b798260b91fd6bb4b31446548a38a2180d161536dc8a3030f857bd` | 22点すべてbottom layer |

ファームウェア側の確認:

- `boards/shields/chipper/chipper.dtsi` は `diode-direction = "col2row";`
- JonMuller READMEのPCBA想定と矛盾しないため、diode directionは発注ブロッカーではない

メモ:

- 回路図上は1枚あたり21キー。左右は同じ `Reverso` 基板を反転して使う前提に見える
- 1台作るには最低2枚の使用可能なPCBが必要
- JLCPCBの最小発注枚数が2枚より多い場合は予備として扱う
- Gerber zip内に `corne-chocolate-VScore.gbr` が含まれるため、注文画面で追加料金やパネル扱いの警告が出ないか確認する
- 公開情報では、作者はJoy-Con系バッテリーを使い、XIAOを直接基板へマウントしている

## 発注方針

### 実施: PCB + 部分PCBA

理由:

- 手はんだでミスしやすいSMDダイオード21個/枚を減らせる
- バッテリーコネクタも小さいため、JLCPCB側で実装できるなら任せたい
- XIAOやスイッチ周りは自分で触るので、組み立て経験は残る

JLCPCBで実施したこと:

1. `GERBER-corne-choc-xiao.zip` をアップロードする
2. PCB previewで外形、穴、左右用に使える枚数を確認する
3. PCB Assemblyを有効化する
4. `BOM-corne-choc-xiao.csv` と `CPL-corne-choc-xiao.csv` をアップロードする
5. 実装対象が `D1`-`D21` と `J8` だけになっていることを確認する
6. 部品配置previewで、ダイオードの向きと `J8` の向きを目視確認する
7. LCSC部品 `C2972761` と `C505023` の在庫、価格、代替提案を確認する
8. `C2972761` が JKSEMI `1N4148SOD-323`、SOD-323、single diodeとして認識されていることを確認する
9. `C505023` がMolex `78171-0002` 相当、Pico-EZmate 1.2mm pitch、2 contactsとして認識されていることを確認する
10. 問題がないことを確認して、部分PCBAで発注する

### フォールバック: PCBのみ（今回は未採用）

次のどれかに当てはまる場合はPCBのみで発注する。

- JLCPCBの部品照合で `C2972761` または `C505023` が使えない
- PCBA追加費用が高すぎる
- 配置previewでダイオードやコネクタの向きに確信が持てない

PCBのみの場合の注意:

- ダイオードのマーカーはsquare through hole側へ向ける
- 逆向きに実装した場合はZMK側のmatrix direction調整が必要になる
- `J8` を使わず、代替のバッテリー接続パッドを使うかも決める

## レビュー反映

| 観点 | 状態 | 判断 |
| ---- | ---- | ---- |
| diode direction | 解消済み | `chipper.dtsi` が `col2row`。PCBA想定と一致する |
| `D1`-`D21` ダイオード | 解消済み | `C2972761` は JKSEMI `1N4148SOD-323`。BOM上の `Footprint=Diode-dual` は部品名ではなくfootprint名として扱う |
| `J8` バッテリーコネクタ | 部品購入前確認 | `C505023` はMolex `78171-0002` / Pico-EZmate 1.2mm / 2 contacts。一般的なJST-PH 2.0mm LiPoとは別物として扱う |
| XIAO direct mount | 組み立て前確認 | 公開情報ではdirect mount前提。ソケット化は初号機では採用しない方向で組み立て手順を確認する |
| リセットスイッチ | 追加購入しない | 公開BOM/CPLには独立したreset switchがない。XIAO側のreset操作で対応する |
| 電源スイッチ | 部品購入前確認 | `SW23` はGerber上でthrough-hole footprint。3 electrical pins + 2 mounting holesのslide switchとして照合する |

## 基板発注で来るもの

| 項目 | 数量 | 入手方法 | 状態 | メモ |
| ---- | ---- | ---- | ---- | ---- |
| `Corne-XIAO Reverso` PCB | 発注5枚 / 使用分2枚 | JLCPCB | 発注済み | 余りは予備。左右は同一基板を反転して使う想定 |

## 実装サービスに任せるもの

公開BOM/CPL上の部品だけを対象にする。

| 項目 | Reference | 1枚あたり | 1台分 | LCSC | 状態 | メモ |
| ---- | ---- | ----: | ----: | ---- | ---- | ---- |
| 1N4148 SOD-323ダイオード | `D1`-`D21` | 21 | 42 | `C2972761` | PCBA発注済み | JKSEMI `1N4148SOD-323`。matrix用。bottom layer |
| バッテリーコネクタ | `J8` | 1 | 2 | `C505023` | PCBA発注済み | Molex `78171-0002` 相当。Pico-EZmate 1.2mm pitch、2 contacts |

## 自分で買うもの

| 項目 | 数量 | 状態 | メモ |
| ---- | ----: | ---- | ---- |
| Seeed Studio XIAO nRF52840 | 3 | 購入済み | 秋月 `Seeed XIAO BLE nRF52840` / 型番 `102010448`。無印。Sense/Plusではない。左右2個 + 予備1個 |
| Kailh Choc v1 Red Pro | 70 | 購入済み | 遊舎工房。赤軸完売のためRed Pro / 35pcs x2を購入。Choc V1互換の軽いリニア軸 |
| Choc v1 hot-swap socket | 50 | 購入済み | 遊舎工房 `Kailh Switch Socket`。`Kailh Choc ロープロファイル用（10個）` x5。型番 `CPG135001S30` |
| MBK Choc Low-Profile 1U keycap | 50 | 購入済み | 遊舎工房。`1U（10個）` x5。Black。寸法 `17.5x16.5mm` |
| MBK Choc Low-Profile 1U Homing keycap | 2 | 購入済み | 遊舎工房。Black。左右ホームポジション用。通常1Uと置き換えて使い、余った1Uは予備 |
| LiPoバッテリー | 2 | 後回し | Joy-Con系/HAC-006候補。`J8` を使うならPico-EZmate 1.2mm側に合うケーブル/極性が必要。基板到着後に確認する |
| 電源スイッチ | 2 | 後回し | `SW23` に合うthrough-hole SPDT slide switch。基板到着後にfootprint寸法と照合して買う |
| XIAO直付け用の消耗品 | 2セット | 組み立て前確認 | ソケット化せずdirect mount前提。裏面バッテリーパッドへのジャンパー配線手順を確認する |
| ケース / ボトムプレート | 左右1セット | 後回し | まずは動作優先。必要ならJonMuller/LeducHのcase SVGを使う |
| ネジ / スペーサー / ゴム足 | 1セット | 後回し | ケース構成に合わせて決める |
| 予備ダイオード | 少量 | 任意 | PCBのみ発注へ切り替えた場合に必要。PCBAなら基本不要 |
| 予備バッテリーコネクタ | 少量 | 任意 | PCBのみ発注へ切り替えた場合に必要 |

購入時の注意:

- XIAOは `Sense` / `Plus` / `ESP32系` と取り違えない
- XIAOはdirect mountするため、ピンヘッダ実装済み品は避ける
- `Kailh Switch Socket` は初期表示がMX用の場合があるため、カート投入前に `Kailh Choc ロープロファイル用（10個）` を確認する
- キーキャップはChoc V1対応の1Uを選ぶ。19x19mm/MX spacing系は使わない
- 安く済ませる代替としてKailhロープロ無刻印1Uも可。ただし `クリア` は形状が異なるためp01では避ける

買わないもの:

- XIAO nRF52840 Plus
- nice!nano
- OLED / nice!view
- RGB LED
- トラックボール部品
- エンコーダー
- TRRSジャック
- BLEドングル

## 発注時チェック

- [x] `GERBER-corne-choc-xiao.zip` がJonMuller正本のものか確認する
- [x] JLCPCBのpreviewで、左右分が同一データ内に面付けされていることを確認する
- [x] usable PCBが最低2枚ある注文になっているか確認する
- [x] PCBA対象が `D1`-`D21` と `J8` だけか確認する
- [x] `C2972761` が JKSEMI `1N4148SOD-323`、SOD-323、single diodeとして照合されるか確認する
- [x] `D1`-`D21` の向きが公開READMEの注意と矛盾しないか確認する
- [x] JLCPCBの部品配置previewでダイオードが各パッド上に載っていることを確認する
- [x] `J8` の向き、コネクタ型番を確認する
- [x] JLCPCBが `J8` に代替部品を提案していないことを確認する
- [x] Choc V1互換スイッチを買う。赤軸は完売のためRed Pro / 35pcs x2で進める
- [x] Choc標準18x17mmキーキャップを買う。19x19mmは避ける
- バッテリー接続前に、届いた基板の `J8` とXIAO側バッテリー配線をテスターで確認する
- XIAOをdirect mountする前提で、裏面パッドへの配線手順をビルド写真で確認する
- XIAOをはんだ付けする前に、シルク、USB-C端子向き、左右反転時の表裏を照合する
- 電源スイッチは、購入前に `SW23` footprintと寸法を照合する

## 電源スイッチ `SW23` footprintメモ

Gerber上の `SW23` はpaste layerに出ておらず、solder maskとPTH drillに出ているため、through-hole実装のslide switchとして扱う。

確認できた穴配置:

| 用途 | 数 | Drill | Pitch / span | メモ |
| ---- | --: | ---- | ---- | ---- |
| electrical pins | 3 | 約0.8mm | 約2.0mm pitch | 中央3穴 |
| mounting holes | 2 | 約1.5mm | 外側間約8.2mm | 両端の固定穴 |

購入候補は、3 electrical pins + 2 mounting holesのSPDT slide switchに限定する。JonMuller READMEのAmazonリンクは参考にするが、商品ページが変わる可能性があるため、最終的には寸法で照合する。

## 参照

- JonMuller `corne-choc-xiao`: <https://github.com/JonMuller/gerbers/tree/main/corne-choc-xiao>
- LeducH整理版: <https://github.com/LeducH/corne-choc-xiao>
- Abomination v1.2: <https://kbd.news/Abomination-v1.2-1936.html>
- JonMuller build discussion: <https://www.reddit.com/r/ErgoMechKeyboards/comments/11ozztx/choc_spaced_corne_xiao/>
- 秋月 Seeed XIAO BLE nRF52840: <https://akizukidenshi.com/catalog/g/g117341/>
- 遊舎工房 Kailhロープロファイルスイッチ: <https://shop.yushakobo.jp/products/pg1350>
- 遊舎工房 Kailh Switch Socket: <https://shop.yushakobo.jp/products/a01ps>
- 遊舎工房 MBK Choc Low-Profile Keycaps: <https://shop.yushakobo.jp/products/mbk-choc-low-profile-keycaps>
- 遊舎工房 Kailhロープロ無刻印キーキャップ1U: <https://shop.yushakobo.jp/products/pg1350cap-blank>
- JKSEMI `1N4148SOD-323`: <https://www.lcsc.com/product-detail/C2972761.html>
- Molex `78171-0002`: <https://www.newark.com/molex/78171-0002/wire-to-board-connector-pico-ezmate/dp/96W3687>
- Molex `781710002` / `C505023`: <https://www.lcsc.com/product-detail/C505023.html>
- JLCPCB BOM/CPL preparation: <https://jlcpcb.com/help/article/advice-for-bom-and-cpl-files-preparation>
- JLCPCB assembly file checklist: <https://jlcpcb.com/blog/files-needed-for-pcb-assembly>

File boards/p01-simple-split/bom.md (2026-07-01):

# BOM

初号機の部品表。

発注・購入時の正本は [parts.md](./parts.md) とする。このファイルは概要だけを残す。

| 種別 | 部品 | 数量 | メモ |
| ---- | ---- | ---- | ---- |
| PCB | JonMuller `corne-choc-xiao` | 使用分2枚 | `GERBER-corne-choc-xiao.zip` をJLCPCBへアップロード |
| PCBA | 1N4148 SOD-323ダイオード / バッテリーコネクタ | 1台分 | BOM/CPLに含まれる `D1`-`D21` と `J8` だけ実装サービス候補 |
| MCU | Seeed Studio XIAO nRF52840 | 2 | 左右用。既存Corne Xiao系シールドとの互換性を優先 |
| スイッチ | Kailh Choc v1 Red | 42 + 予備 | 50個買うと余裕がある |
| キーキャップ | Choc標準18x17mm | 42 | 19x19mm/MX spacing系は避ける |
| ホットスワップソケット | Choc v1対応 | 42 + 予備 | footprint適合を確認 |
| バッテリー | 未定 | 2 | Joy-Con系/HAC-006候補。`J8` に合うケーブル/極性を確認 |
| 電源スイッチ | 未定 | 2 | `SW23` footprintに合うthrough-hole SPDT slide switch |
| リセットスイッチ | なし | 0 | p01では別体リセットスイッチを買わない想定 |
| XIAOソケット | なし | 0 | p01ではdirect mount前提 |
| ケース / プレート | 未定 | 左右1セット | 最初は簡易構成でよい |
| ネジ / スペーサー | 未定 | 1セット | ケースやプレート構成に合わせる |

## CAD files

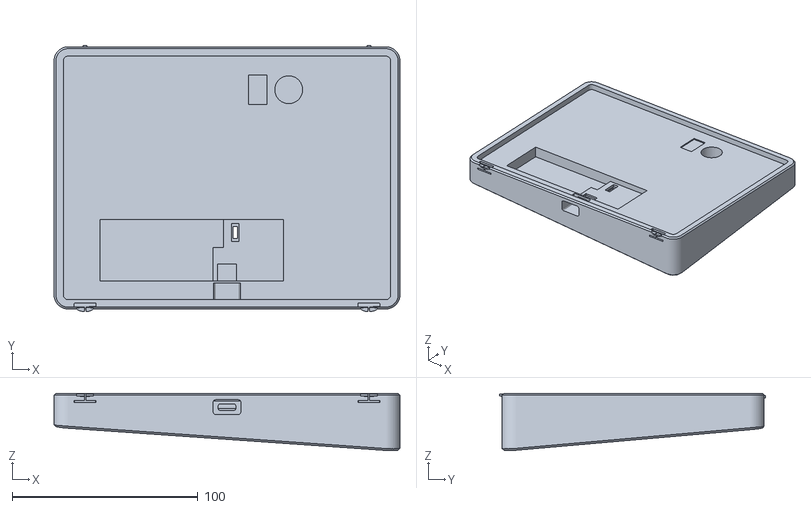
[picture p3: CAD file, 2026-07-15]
boards/p02-auto-kdk/generated/case/split-us60pct-right-bottom-case.stl
186.4 x 143.5 x 31.0

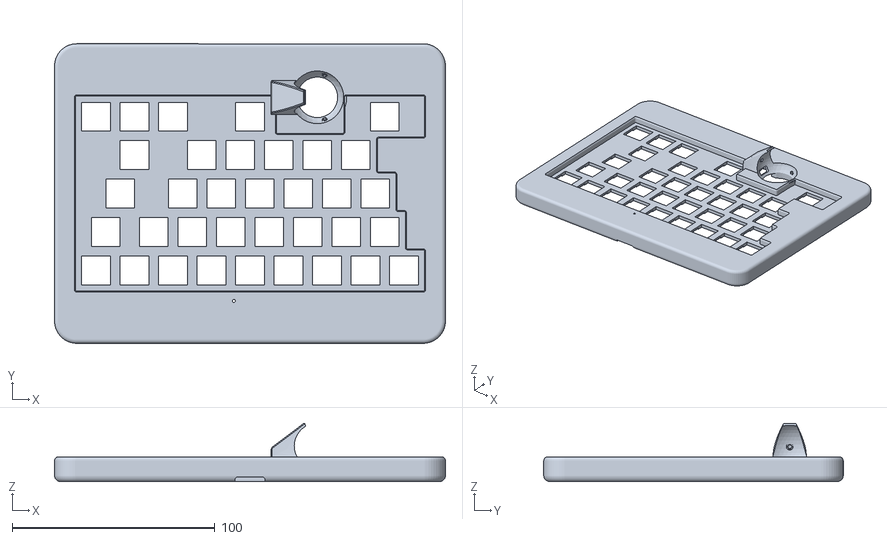
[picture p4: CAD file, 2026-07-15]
boards/p02-auto-kdk/generated/case/split-us60pct-right-top-case.stl
193.0 x 147.9 x 28.7

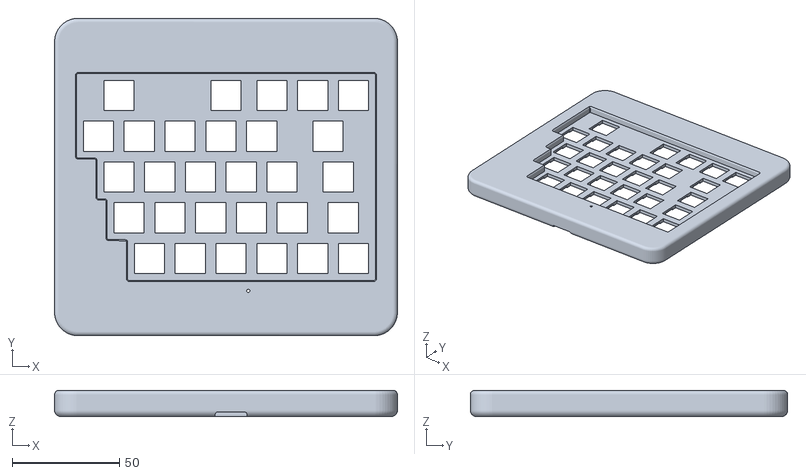
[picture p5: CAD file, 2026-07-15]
boards/p02-auto-kdk/generated/case/split-us60pct-left-top-case.stl
159.8 x 147.9 x 12.2

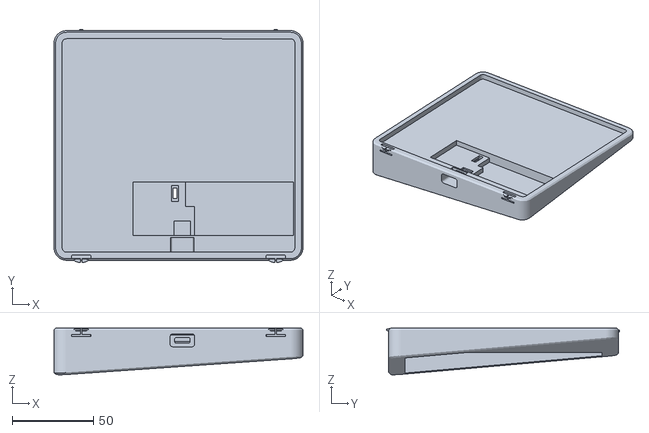
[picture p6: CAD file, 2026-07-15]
boards/p02-auto-kdk/generated/case/split-us60pct-left-bottom-case.stl
153.1 x 143.5 x 28.7

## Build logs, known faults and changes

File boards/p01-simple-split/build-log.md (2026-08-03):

# Build Log

組み立て、失敗、変更、気づきを時系列で記録する。

## ログ

- 2026-06-30: `firmware/zmk-config/` に `wintinue/zmk-corne` を取り込み。取り込み元commitは `0236c3a9f466411806be85f202e3c509db495592`。
- 2026-06-30: `firmware/zmk-config/build.yaml` のboard名を `seeeduino_xiao_ble` から `xiao_ble//zmk` に更新。
- 2026-06-30: p01用ZMK configをGitHub Actionsでビルドするroot workflow `.github/workflows/p01-zmk-build.yml` を追加。
- 2026-06-30: GitHub Actions初回実行は、ZMKの再利用workflowがネストした `zmk-config` 配置を前提にしておらず `west update` で失敗。p01専用workflowに差し替え、左右のUF2だけをビルドする構成に変更。
- 2026-06-30: GitHub Actions run `28447236060` が成功。artifact `p01-zmk-firmware` に `chipper_left-xiao_ble-zmk.uf2` と `chipper_right-xiao_ble-zmk.uf2` が出ることを確認。
- 2026-07-01: JonMuller `corne-choc-xiao` のGerber/BOM/CPLを固定し、PCB + 部分PCBAを第一候補にした発注・購入チェックリスト `parts.md` を作成。
- 2026-07-01: レビュー結果を反映。`chipper.dtsi` の `diode-direction` は `col2row` でPCBA想定と一致。`J8` はPico-EZmate 1.2mm系として扱い、XIAOはdirect mount前提で発注前チェックに追加。
- 2026-07-01: 再レビュー結果を反映。`C2972761` は JKSEMI `1N4148SOD-323` と特定。`SW23` はGerberからthrough-hole SPDT slide switch footprintとして寸法メモを追加。
- 2026-07-01: JLCPCBへPCB + bottom side部分PCBAで発注。PCB 5枚、PCBA 5枚、green / 1.6mm / HASL with lead、面付け済み、different designs 2。BOM/CPL照合は `C2972761` と `C505023` の2部品だけ、配置previewで `D1`-`D21` と `J8` のbottom配置を確認済み。
- 2026-07-01: 遊舎工房でChocソケット50個、MBK 1U Black 50個、MBK 1U Homing Black 2個、Kailh Choc v1 Red Pro 70個を購入。赤軸は完売だったため、p01はRed Proで進める。
- 2026-07-01: 秋月でSeeed XIAO BLE nRF52840を3個購入。p01は左右で2個使い、残り1個はdirect mount失敗時の予備にする。
- 2026-07-11: 注文した部品がすべて到着。JLCPCBのPCB + 部分PCBA（`D1`-`D21`、`J8` 実装済み）、Chocソケット、スイッチ、キーキャップ、XIAO。次はXIAO単体の書き込みテストから組み立てに入る。
- 2026-07-12: XIAO 1個目（serial `B687D5B1468A18A7`）の書き込みテスト成功。RSTダブルタップで `XIAO-SENSE` マウント（UF2 Bootloader 0.6.1 / SoftDevice S140 7.3.0）→ `chipper_left-xiao_ble-zmk.uf2` をコピー → USB上で `Chipper`（VID 0x1d50 / PID 0x615e）のHIDキーボードとして認識。工場出荷ファームは1200bpsタッチ非対応で、ブートローダ移行は物理RSTダブルタップが必要。
- 2026-07-12: XIAO 2個目の書き込みテスト成功。同じ手順で `chipper_right-xiao_ble-zmk.uf2` を書き込み、USB上で `Chipper Right` として認識。個体に油性ペンでL/Rを記入済み。3個目は予備として未書き込みのまま。
- 2026-07-13: はんだ付け前の机上split疎通テスト成功。左XIAOをPCへUSB接続（central、`Chipper` として認識）、右XIAOを別ポートで給電し、右XIAOの `0`（P0.02 / Row0）と `6`（P1.11 / Col0）のパッドをピンセットで短絡 → PCに `y` が入力された。右のキースキャン → BLE split → 左central → USB HIDの全経路が動作。ジャンパー/ピンセット短絡はRC(0,6)=`Y` に対応（右はcol-offset 6）。左単体も `0`×`6`（Col5）短絡で RC(0,5)=`T` の入力を確認。左右ともスキャン動作OK、組み立て前のファーム・無線・HID検証はすべて完了。
- 2026-07-13: テスターとしてHIOKI 3244-60（カードハイテスタ）を購入。PCB検品・ソケットはんだ付け後の導通確認に使う。
- 2026-07-14: 左手側PCBのChocソケットはんだ付け完了。HIOKI 3244-60も到着。次はテスターでソケットの導通確認をしてから、スイッチを挿して左手側の実キー入力テストに進む。
- 2026-07-14: 左手側にスイッチを全装着し、HIOKI 3244-60の導通ブザーで全21キーを検品。各ソケットの2つのはんだ点にプローブを当ててスイッチを押すと鳴る・離すと止まるを全キーで確認、ソケットはんだは全数OK。キー確認用ツール `tools/keytest.html`（押したキーが緑に光るローカルページ）を追加。次は左XIAOのdirect mountはんだ付け。Reverso基板のため取り付け面をシルクで要確認。
- 2026-07-14: 右手側もソケットはんだ付け・スイッチ全装着・テスターのブザー検品21キー全数合格。これで左右42キーぶんのソケットはんだは全数OK。XIAOは左右とも未装着で、次は両XIAO（`L`/`R` 記入済み・ファーム書き込み済み）のdirect mountはんだ付け → keytest.htmlでの実入力テスト。
- 2026-08-03: **p01を未完成のまま保留にする判断**（下記「保留」節を参照）。

## 保留（2026-08-03）

**XIAOのdirect mountはんだ付け直前で停止し、完成させない。** 放置ではなく判断として記録する。

**残作業**: XIAO 2個のdirect mountはんだ付けのみ（追加出費ゼロ・作業1〜2時間）。部品はすべて手元にあり、ファーム書き込み・机上split疎通テストまで完了済み。

**それでも完成させない理由**:

- **学習目的はすべて達成済み**。ZMK（shield定義・build.yaml・GitHub Actionsビルド・キーマップ）、BLE split疎通、Chocソケットのはんだ付けと導通検品42キー、JLCPCBのPCB＋部分PCBA発注（Gerber/BOM/CPL照合）は全部通した。残るdirect mountだけが未経験だが、**p03では自分のPCBにMCUを載せる設計をする**ため、既製ボードを他人のPCBに直付けする経験の転用価値は薄い
- **完成しても日常運用に投入できない**。Corne系42キーの配列は現在の運用（US 60%相当）と別物で、「1週間試しに使ってみる」ができるものではない。完成させて得られるのは達成感のみ
- 使っているChoc v1 RedとMBKキーキャップは、完成版のChoc V2（MXステム）と物理非互換のため部品としても引き継げない

**残る資産**（`docs/decisions.md` の「p01/p02の資産の活用可能性」も参照）:

- **XIAO nRF52840 が3個とも未使用のまま残る**（p01で2個使う予定だったが装着しないため）。p03でXIAO案を採る場合、ZMKボード定義の自作が丸ごと不要になる
- `tools/keytest.html`（キー確認ツール）はそのまま使える
- Chocソケット（CPG135001S30）の余りはChoc V2でも共通で流用可
- PCBは「XIAOのフットプリントと配線の実例」として参照価値がある

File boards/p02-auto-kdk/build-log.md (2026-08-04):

# Build Log

組み立て、失敗、変更、気づきを時系列で記録する。

## ログ

- 2026-08-02: 左右PCBのChocソケットはんだ付け完了。ダイオード64個はJLCPCBのPCBAで工場実装済みのため、自分ではんだ付けするのはソケットのみ。
- 2026-08-02: 動作確認用の暫定キーマップを作成。Auto-KDK生成の `config/keymap.keymap` は**全キー `&none`** で、そのまま書き込むと押しても何も入力されない。US 60%相当の layer_0 と、Fn/Bluetooth の layer_1（`&mo 1` で `F1`〜`F12`・`BT_SEL 0-4`・`BT_CLR`）を記述して zmk-config リポジトリの main に push（`672d54d`）。GitHub Actions run `30730307052` 成功、artifactを `firmware-built/firmware/` に配置。
- 2026-08-02: **コントローラボードは左右鏡像の別部品**と判明。当初「2枚は同一品でファームが役割を決める」と誤認したが、BOOTH商品説明に「形状が対称な2種類のコントローラがセットになっています」と明記されていた。裏面シルクは `AKDK-BT1-1` / `AKDK-BT1-2`。生成PCBデータのフットプリント名は**左手 = `MS88SF2_1-1-3-SIDE2`、右手 = `MS88SF2_1-1-3-SIDE1`**（`pcb/split-us60pct-{left,right}-pcb.json` の LIB 要素）。外形（レール込み）の張り出し方向もコンスルーパッド列を基準に左右反転している。
- 2026-08-02: **コントローラはPCBのソケット実装面（bottom側）に載せる**。スイッチを挿す面ではない。公式の `img/wireless-controller-set.png` でも、紫のChocソケットと黒いダイオードが見える面にコントローラが載っている。構造的にも、トップケースがスイッチプレートを兼ねて上から被さり、コントローラとバッテリーはPCB下の空間に収まる。
- 2026-08-02: コンスルーを加工（無線版付属は11ピン→不要2本を抜いて樹脂をカット）、コントローラのレールをペンチで折り取り、装着。**ボード側のコンスルー穴はマトリクス4列×9行**で、19/18/17/16mmのキーピッチに対応。19mmピッチなので**一番外側（基板の縁に近い）の列**を使う。マウスバイト（ミシン目）の跡が穴と紛らわしいが、コンスルー穴は白いシルク枠の内側にある完全な円、マウスバイト跡は枠の外の半円で別物。
- 2026-08-02: ファームウェア書き込み。**電源スイッチOFFでUSB接続 → `NRF52BOOT` としてマウント**。`cp` は「could not copy extended attributes: Device not configured」で exit 1 を返すが、**ドライブがアンマウントされていれば成功**（READMEにも明記の挙動）。`INFO_UF2.TXT` の Board-ID は左右とも `auto-kdk-nrf52840-1` で、**左右の判別には使えない**。
- 2026-08-02: ZMK起動を確認。USB上の表示は **右(Central) = `split_us60pct` / `ZMK Project`**、**左(Peripheral) = `Generic CDC`**。左が別名なのは `ZMK_KEYBOARD_NAME` が `Kconfig.defconfig` で右手shieldにしか定義されていないため。Peripheral側はHIDを出さずCDCのみ。
- 2026-08-02: 右手35キーのピンセット全数チェック（ソケットの対角2端子を短絡）。**34キーOK、`k` のみ反応せず**。`k` は row2(`akdk_d 17`) × col3(`akdk_d 12`)。同じ行（h・j・l・;・'・Enter）も同じ列（9・i・,）も反応するため、断線はその交点に限定される。追いはんだでは直らず、ダイオードの向きも隣接キーと同じに見えるため原因未特定。**プロトタイプとして1キー欠けたまま先に進む判断**（ケースを閉じる前に再診断する）。
- 2026-08-02: 左手29キー全数OK。左手の入力が右手経由でMacに届くことを確認し、**左右のBLE接続も成立**（初回ペアリングは自動）。
- 2026-08-02: トラックボールのセンサーモジュールのFFCコネクタのラッチを破損（爪で起こそうとして外れた）。**p02ではトラックボールを見送る判断**。完成版ではトラックパッドを検討する方向のため、再購入(¥4,500)せず先に進む。ケースのトラックボール穴は開いたままになる。
- 2026-08-02: **バッテリー DTP502535(PHR) の極性がAuto-KDKコントローラと逆**と判明。ボード側は導通チェック（USB-Cシェル＝GNDとPHコネクタ端子の導通）でシルク通りと確認済み。コネクタのツメで決まる挿し方向では赤線が `−` 側に来るため、そのまま挿すとボードが即死する。コンタクトの差し替えかはんだ付けでの入れ替えが必要。左右でコネクタが鏡像配置なので、右手側は要再確認。

- 2026-08-02: 軸の打ち比べ実施。サンプル3種（Islet 43gf / Pink Island 35gf / Whale 45gfタクタイル）を実機PCBのソケットに挿して比較し、**Kailh Deep Sea Silent MINI Pink Island（35gf 静音リニア）に決定**。当初の本命だったIslet（43gf）を実打鍵で覆した。
- 2026-08-02: バッテリーの極性入れ替えのため線を切ったが、被覆剥きで難航して中断。**剥き出しの芯線は絶縁テープで養生した状態で保留**。p02はUSB給電（右手をMacへ、左手を給電のみ）でも動作するため、バッテリーは完成をブロックしない。
- 2026-08-02: 完成版は**フルスクラッチで設計する方針に決定**。ポインティングデバイスは**Apple Magic Trackpad（現行・感圧式）を左右分割の中央にはめ込む**構成。詳細と論点は `docs/decisions.md` を参照。

- 2026-08-03: **p02を未完成のまま保留にする判断**（下記「保留」節を参照）。

- 2026-08-04: **YUZUキーキャップ到着**。p02実機に挿して打鍵検証を実施。
- 2026-08-04: **スタビなし幅広キー（2U/2.25U）の検証に合格**。キーキャップ込みで問題なく実用に耐えると判断。**レイアウト確定**（split-us60pct・64キーのまま）。キーキャップ再発注の分岐は消滅。
- 2026-08-04: キーキャップ込みで軸を打ち比べ直した結果、**Islet（43gf 静音リニア）が最良**と判断し、8/2のPink Island決定を覆して**Isletに変更**（7/15の当初本命に帰着）。キーキャップの質量が乗ると評価が逆転する。軸の打ち比べは必ずキーキャップ装着で行うこと。

## 保留（2026-08-03）

**p02は完成させない。** 放置ではなく判断として記録する。

**残作業と、それをやらない理由**:

| 残作業 | コスト | やらない理由 |
|---|---|---|
| バッテリーの極性入れ替え | 再工作（1回失敗済み。被覆剥きで難航して中断） | 一度失敗しており、やり直す動機が残らない |
| トラックボール搭載 | モジュール再購入 ¥4,500＋納期 | 完成版ではトラックパッド方針のため、ここで評価しても設計入力にならない |
| 本番スイッチ Pink Island 64個＋予備 | ¥5,000前後 | 下記の通り、全数は不要 |
| スイッチ到着後の組み上げ（ケース・キーキャップ） | 作業数時間 | 上記が揃わないため到達しない |

**判断の根拠**: p03の設計に必要な実測値（左右間隔・奥行きをどこで揃えるか・トラックパッド面とキートップの高さ差・チルト/テント要否）は、**結局p03の実物を3Dプリントして手を乗せないと決まらない**。p02を完成させても代替にはならず、投じるコストに対して得られる設計入力が見合わない。

- 19mmピッチの体感は、MacBookが約19mmなので既に体で分かっている
- 左右間隔はMagic Trackpadの幅160mm＋隙間で数字から決まる

**p02でのみ分かること = スタビなし幅広キー（2U/2.25U）の実用性**。ただし検証対象は左Shift 2.25U・左親指2U・右親指2U・Enter 2.25Uの4箇所＋比較用の1Uが数個なので、**打ち比べで買ったサンプル軸の余りで足りる**（64個の発注は不要）。~~キーキャップが届いた時点で、その数個だけ挿して確かめる。~~ → **検証済み・合格（2026-08-04、上記ログ参照）**。

**p02のケース実物には価値が残る**: 左右の間隔・高さ・角度を実寸で再現できる唯一の現物なので、p03の配置検討モックアップとして使う。中身が未完成でもこの役割は果たせる。

**発注の順序**: 本番スイッチ64個とYUZUキーキャップの発注は、**p03のキー数とレイアウトが確定してから**行う。先に発注すると、p03のPCB論点（XIAOでキー数を減らす vs MDBT50Q直付け）の結論次第で作り直しになる。

> **2026-08-03 更新**: PCB論点は **MDBT50Q直付けに決定**し、ピン制約が消えたため **p03でもp02のレイアウト（split-us60pct・64キー）をほぼそのまま使う**方針になった。よってYUZUキーキャップは流用可能で、再発注の懸念は解消。
> ただし**スタビなし幅広キー（2u/2.25u × 4箇所）の検証がレイアウト確定の最後のピース**として残っている。検証で不合格なら2u/2.25uを1.5u以下に分割することになり、そのときはキー数が増えてキーキャップも作り直しになる。**本番スイッチ64個の発注はこの検証の後**にする。詳細は `docs/decisions.md` の「キーレイアウト」を参照。

**残る資産**: Auto-KDK専用コントローラ2枚はフルスクラッチでは使えないが、Chocソケット・DTP502535バッテリー2本・テスター・ZMK設定の知見・JLCPCB発注の知見はp03に引き継げる（`docs/decisions.md` の「p01/p02の資産の活用可能性」参照）。

## 未完了（保留中・再開する場合のリスト）

- [ ] `k`（右手 row2 × col3）の断線診断と修復
- [ ] バッテリーの極性入れ替え（線を切った状態で中断中。左右それぞれ極性の再確認が必要）→ 接続 → 完全ワイヤレスでの動作確認
- [ ] ~~**本番用スイッチ Pink Island 64個＋予備の発注（クリティカルパス）**~~ → p03のレイアウト確定後に発注する方針に変更（2026-08-03）。レイアウト確定（2026-08-04）により発注可能、軸は**Islet**に変更
- [x] スタビなし幅広キーの実用性検証（サンプル軸の余り＋キーキャップ数個で実施）→ **合格（2026-08-04）**
- [ ] スイッチ到着後: トップケースを挟んでスイッチ取り付け → ボトムケース → キーキャップ・滑り止め

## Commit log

2026-06-30 docs: 段階試作向けに構成を整理
2026-06-30 docs: p01の実行計画を具体化
2026-06-30 docs: p01の基板選定方針を記録
2026-06-30 docs: p01用ZMK configを取り込む
2026-06-30 fix: p01 ZMKのboard指定を更新
2026-06-30 ci: p01 ZMKビルドworkflowを追加
2026-06-30 ci: p01 ZMKビルドをサブディレクトリ対応にする
2026-06-30 docs: p01 ZMKビルド成功を記録
2026-07-01 docs: p01の発注チェックリストを追加
2026-07-01 docs: p01のJLCPCB発注結果を記録
2026-07-01 docs: p01の部品購入結果を記録
2026-07-13 docs: p01のはんだ付け前split疎通テスト成功を記録
2026-07-13 docs: Auto-KDKの比較検討をtarget PCB設計時に行う方針を記録
2026-07-14 docs: 左手側ソケットはんだ付け完了とHIOKI 3244-60到着を記録
2026-07-14 docs: 左手側21キーのテスター検品全数OKを記録、keytest.htmlを追加
2026-07-14 docs: 右手側もソケット検品21キー全数合格、左右XIAOは未装着と記録
2026-07-15 docs: Auto-KDK採用を決定、スイッチChoc V2化・エンコーダー廃止等をdecisions/roadmapに反映、p02設計JSONを追加
2026-07-15 docs: キーキャップ方針をYUZU注文(PFFプロファイル)に更新
2026-07-15 docs: p02設計JSONを更新(Choc V2化・トラックボール位置調整・Row設定完了)、.gitignore追加
2026-07-15 docs: ケースのマウントタイプをインテグレーテッドに決定
2026-07-15 docs: トラックパッドジェスチャ代替のZMKコンボ割り当てを記録
2026-07-15 docs: p02ケースパラメータ確定(チルト5°/テント4°/丸型R面取り等)を記録
2026-07-15 docs: p02設計JSON更新(トラックボール180°回転・位置調整・ケースパラメータ確定版)
2026-07-15 docs: Auto-KDK生成データ一式を追加、発注前チェック結果(ライセンス/ソケット解決・スタビ無し判明)を記録
    [split-us60pct-left-bottom-case.stl, split-us60pct-left-top-case.stl, split-us60pct-right-bottom-case.stl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]
2026-07-15 docs: 幅広キーはスタビなしで行く方針を決定(p02の検証項目化)
2026-07-15 chore: firmware/(zmk-config入れ子リポジトリ)をgitignoreに追加
2026-07-15 docs: 接続方式を「まずBLE直結、必要時にドングル追加」に変更
2026-07-15 docs: YUZU PFFで全キー幅が揃うことを確認、発注前チェックを消化
2026-07-15 docs: ドングル構成のビルド検証成功(XIAO転用含む)を記録
2026-07-15 docs: YUZUキーキャップデザイン確定(GR1×GR2/Noto Sans/Framework7/PFF)、デザインJSONを保存
2026-07-15 docs: YUZUデザイン微調整(残存cmdテキスト掃除、tabキーをアイコン化)
2026-07-15 docs: p02発注チェックリスト(orders.md)を作成
2026-07-15 docs: ダイオードは工場実装(PCBA bottom side)に決定、orders.mdを更新
2026-07-15 docs: orders.mdを決定済み✅と要検討に整理、スナップ方向の確認事項を追加
2026-07-15 docs: 軸の本命をDeep Sea Silent Mini Isletに決定、サンプル4種の打ち比べ計画をorders.mdに記録
2026-07-15 docs: バッテリーをDTP502535(PHR)×2に決定、極性チェック手順を記録
2026-07-15 docs: スナップ方向はhorizontal限定が現行仕様と判明、対応不要として解決
2026-07-15 docs: 発注リストに商品URL・トラックボール追加部品(支持球/FFC)を反映
2026-07-15 docs: BOOTH発注完了(コントローラ/センサーモジュール/25mm球)を記録
2026-07-15 docs: TALP(Whale5個)と共立(バッテリー2本)の発注完了を記録
2026-07-15 docs: 遊舎工房発注完了(Islet/Pink各3・ソケット70個)、Red基準器はp01のChoc v1 Redで代用と記録
2026-07-15 docs: Amazonの小物(セラミック球/FFCケーブル)の具体URLをorders.mdに記録
2026-07-15 docs: 木工用ボンド・マスキングテープのURLを追加、爪楊枝は手持ち確認済み
2026-07-15 docs: バッテリー固定用ビニールテープ(README推奨)を買い物リストに追加
2026-07-15 docs: ビニールテープのAmazon URLを追加
2026-07-15 docs: ビニールテープを安価な単巻(3M 117)に差し替え
2026-07-15 docs: マスキングテープ・ビニールテープはCan Doで購入する方針に変更
2026-07-15 docs: 滑り止めはGRIPLUS極薄シールに決定、USB-Cケーブルは手持ち確認済み
2026-07-15 docs: Amazon発注完了(セラミック球/FFC/ボンド/滑り止め)を記録
2026-07-15 docs: YUZU注文タイミングを「DRC通過後すぐ」に修正(発送待ちは不要と整理)
2026-07-15 chore: 派生zipをgitignoreに追加
2026-07-15 docs: JLCPCB PCB+PCBA発注完了($56.26)を記録、B完了
2026-07-15 docs: YUZUキーキャップ発注完了(#K0D7MHFD8, $78.90)を記録、E完了
2026-07-15 docs: JLC3DPケース注文提出(JLC Black Resin, W2026071523545461)を記録、素材決定をLEDO白→JLC黒に変更
2026-07-15 docs: JLCPCB/JLC3DP発注の癖をCLAUDE.mdに記録
2026-07-17 docs: JLC3DPレビュー問い合わせ(薄壁リスク確認)への承諾返信を記録
2026-07-29 docs: 完成版の薄型化・電源方式の検討メモを追記
2026-07-29 docs: 乾電池案のセンサー電圧調査結果(PAW3222/のぎけす屋モジュール)を検討メモに追記
2026-08-03 docs: p02組み立て記録(build-log)を追加、軸をPink Islandに決定、完成版はフルスクラッチ方針へ
    p02の組み立てを左右のコントローラ装着・ファーム書き込み・キー全数チェックまで実施。
    - build-log.md を新規作成し、当日の作業と判明した癖を時系列で記録
    - コントローラ2枚は左右鏡像の別部品(左=SIDE2 / 右=SIDE1)
    - コントローラはソケット実装面(bottom側)に載せる
    - キー確認: 右手34/35(kのみNG)、左手29/29、左右のBLE接続も成立
    - 軸を Kailh Deep Sea Silent MINI Pink Island(35gf静音リニア)に決定
    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
2026-08-03 docs: 中央トラックパッド統合ケースの設計メモをdecisions.mdへ集約、target.mdを旧方針と明記
2026-08-03 docs: p01/p02の保留を判断として記録、Nuio実運用経験の裏付け・乾電池案の本命化・複数Mac切り替え論点を追加
2026-08-03 docs: トラックパッドの複数Mac切り替えをblueutil+ZMKマクロのソフト方式に決定、有線+切替器案はフォールバックへ
2026-08-03 docs: MCU選択肢を5案に整理(価格/技適/乾電池適合)、アンテナ設計とボード定義自作のハードル評価を下げる
2026-08-03 docs: MCUをMDBT50Q直付けに決定、電源をエネループ単4x2に確定、厚み目標を現実的な目標へ格上げ
2026-08-03 docs: キーレイアウトはp02のsplit-us60pctを流用と決定、トラックボール廃止後の扱いとスタビなし検証の位置づけを整理
2026-08-03 docs: roadmapをp03(中央トラックパッド統合・フルスクラッチ)中心に全面改訂、p01/p02を保留として整理
2026-08-03 docs: READMEを現行方針(トラックパッド統合/MDBT50Q/乾電池/Choc V2)に更新、p01とtargetに旧方針の注記を追加
2026-08-03 docs: p02の到達点の記述を訂正(スイッチ未装着で打鍵不可)、旧「p02を完成させる」進め方を撤回
2026-08-04 docs: 振り返りの知見をCLAUDE.mdに追加(物理作業の進め方・発注前チェック)
    - 「物理作業の進め方」セクションを新設
    - 部品の左右/向き/極性を写真の目視で断定せず、設計データとベンダー記載で裏を取る
    - 物理的な疑問はSTL/EasyEDA JSONをパースして数値で答える
    - 「発注の癖」を親セクションにし、業者に依らないルールを追加
    - 発注前に向き・極性・互換性を確認する(p02で詰まった箇所は全部この型だった)
    - 既存のJLCPCB/JLC3DPの内容は子セクションへ
2026-08-04 docs: キーキャップ込み打鍵で軸をIsletに変更、スタビなし幅広キー検証合格でレイアウト確定
2026-08-27 docs: Magic Trackpad(USB-C ブラック)購入を記録、p03フェーズ0を更新
2026-09-03 docs: XELBOをウォッチ対象に記録、プロジェクトを一時休止（再開目安はXELBO販売開始）
